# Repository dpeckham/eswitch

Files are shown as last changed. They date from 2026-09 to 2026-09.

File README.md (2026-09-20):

# eswitch — eight-channel house-bank load switch

ESP32-S3 controlled high-side switch with one ATO fuse per channel. Each three-clip
holder accepts a fuse in AUTO (through the PROFET) or BYPASS (direct to the load).

The main KiCad project contains the **334 × 172 mm revision-C design**, with an
independent hardware latch in each channel ahead of both fuse positions. A short
is handled locally; healthy outputs and logic retain their shared supply. See
[circuit and limits](docs/channel-isolation-review.md), the authoritative
[release status](docs/release-status.json), and [BOM cost per board](docs/bom-cost.md).

**Revision C is released for prototype fabrication.** Use the
[bare-board upload ZIP](fab/revision-c/eswitch-revC-gerbers.zip) and
[complete build package](fab/revision-c/eswitch-revC-build-package.zip).
[Order settings and release evidence](fab/revision-c/README.md) accompany them.
ERC, DRC including warnings, routing and schematic parity are all clean;
29 transient cases pass. Bench qualification remains required before service.

The revision-B fabrication release is withdrawn. Its historical ZIP does not
implement the new fault-isolation requirement.

| Item | Requirement |
|---|---|
| Supply | 9.5–16 V; nominal 12 V house bank |
| Simultaneous load | 40 A continuous target, not a qualified rating |
| Channels | CH1–2: 10 A fuse maximum; CH3–7: 5 A; CH8: 20 A |
| Main fuse | Upstream protection; no onboard main fuse; F9 is logic-only, maximum 2 A |
| Outputs | Eight Wuerth 691218410002 direct-entry blocks; pin 1 GND, pin 2 LOAD+ |
| Inputs | Two Wuerth 74650195 M5 ring-lug terminals |
| PCB | 334 × 172 mm, JLCPCB JLC041622-3313, four layers, 2 oz outer/inner, 1.6 mm nominal, ENIG |
| Assembly | Three boards, manual paste + hot air/hot plate; validate one first |
| Procurement | Exact DigiKey MPNs; dated stock is not a reservation and must be refreshed |

Fuse labels identify circuit numbers and maximum fuse values, not guaranteed
continuous currents. USB is for initial bench programming **with battery power
disconnected**; subsequent updates are OTA. Mixed AUTO/BYPASS startup is required.
See [agreed scope](docs/design-constraints.md); deferred installation details have
not been silently assumed.

```sh
mise install
mise exec -- just verify          # saved schematic/PCB; ERC, DRC, parity, pin/silk/geometry checks
mise exec -- just all             # verify + renders; preserves completed routing
mise exec -- just review-package  # clearly unreleased CAM/BOM/schematic/assembly drawing ZIP
mise exec -- just bom             # requires fresh stock evidence; fails when stale
mise exec -- just package         # also requires engineering release for these exact source hashes
python3 -m unittest discover -s tools -p 'test_*.py'
```

`out/verification/manifest.json` binds verification results to the exact source
files and report hashes, including the engineering release documents. The
withdrawn prototype ZIP is retained under `fab/revision-b/` for traceability.
`out/review/` retains an unreleased review snapshot; do not upload it.
`fab/legacy-f76c39e/` and the old OSH Park upload are obsolete.
No order or purchase has been made.

The saved PCB is the authoritative routed design. `just pcb` now creates an
**unrouted candidate under out/**. `just libs` and `just sch` are explicit source
regeneration operations. Checked finish/routing tools replace the old revision-A
coordinate patches in the build recipes. Do not run legacy `finish.py`/`stitch.py`
on revision C. Its one-time migration uses the explicitly saved revision-B snapshot.

[Assembly instructions](docs/assembly.md) · [Channel/input protection](docs/channel-isolation-review.md)
· [Critical review/history](docs/critical-review.md) · [Per-board BOM](fab/digikey/eswitch-digikey-bom.csv)

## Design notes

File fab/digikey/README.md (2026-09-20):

# DigiKey BOM — quantities for ONE module

This is the revision-C BOM, including independent channel breakers. Check
[current release status](../../docs/release-status.json) for fabrication readiness.
[Cost per board](../../docs/bom-cost.md) includes a priced breakdown and an optional
cart with spares where price breaks reduce the total cash cost.

`eswitch-digikey-bom.csv` lists the exact parts needed to assemble **one board**.
Apply your desired number of modules when ordering. No batch multiplier or spare
allowance is included, even though the prototype plan is to build three modules.

Quantity checks: 1 ESP32 module, 24 Keystone 3557 clips, 8 output connectors,
2 input terminals, and 8 branch fuse inserts per board. The clip quantity counts
individual clips, not complete fuse holders.

For manual assembly, choose cut tape (CT) for surface-mount parts where offered,
and the listed bulk/tray packaging otherwise. Digi-Reel fees and full-reel minimum
quantities are unnecessary for this build. Check quantity breaks in the cart:
occasionally a few extra parts cost less than the exact required quantity.

`stock-audit.csv` is a dated inventory observation, not a price quote or stock
reservation. No parts have been purchased here. Installation wiring, input
ring lugs/screws and enclosure hardware are outside this component BOM.

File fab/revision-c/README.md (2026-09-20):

# Revision C — released for prototype fabrication

Upload **[eswitch-revC-gerbers.zip](eswitch-revC-gerbers.zip)** for bare PCBs.
The **[complete build package](eswitch-revC-build-package.zip)** contains the
schematic, 1:1 assembly drawings, BOM, cost breakdown, engineering limits and
verification evidence. Revision-B packages are withdrawn.

The revised board is **334 × 172 mm**. All eight channels have independent
hardware latches ahead of both AUTO and BYPASS. USB edge alignment, exposed-pad
thermal vias, input source vias, twelve mounting holes with hardware clearances,
Kelvin sensing, monitoring, local reset buttons and test points are included.

## Order settings

| Setting | Required value |
|---|---|
| Board | FR-4, four layers, 334 × 172 mm, single PCB |
| Quantity | Five bare PCBs is the offered batch covering three planned assemblies |
| Thickness | 1.6 mm nominal; JLC041622-3313 stackup |
| Copper | **2 oz outer AND inner** |
| Finish / mask / legend | ENIG 1 µin / green / white |
| USB impedance | 90 Ω differential, ±10%; supplied USB-impedance-request.jpg |
| Via covering | Plugged for eligible closed-mask vias only; preserve exposed thermal pads |
| Min via selection | 0.3 mm hole / 0.4–0.45 mm diameter offered option |
| Production files | Confirm Production File = Yes; **disable automatic confirmation** |
| Electrical test | Flying Probe Fully Test |
| Mark | Remove Mark |
| Assembly / stencil | Not ordered; manual assembly plan in build package |

Use the exact layer order F.Cu / In1.Cu / In2.Cu / B.Cu. Preserve separate
PTH/NPTH drills and all supplied pad/mask openings. Read `gerbers/README-fab.txt`
for the complete specification. JLC can reset finish and stackup settings after
an upload: check these values **after** uploading. Approve the manufacturer's
production files manually, including any proposed USB impedance adjustments.

## Checks and remaining qualification

KiCad 10.0.6 ERC, DRC including warnings, unrouted connections and schematic/PCB
parity all pass with zero findings. The native 1195-pin map, fuse geometry and
silkscreen, mounting clearances and 3276 USB reference samples pass. All 29
bounded startup/fault transient cases pass. These are calculations and simulation,
not measurements of an assembled board.

Independent Gerber/Excellon parsing verifies four copper layers, the outline,
1579 plated drill objects and 14 non-plated holes. Exported copper/mask/silk and
top/bottom 3D views were inspected. [CAM evidence](cam-review.json) binds the
final flat upload ZIP to the inspected export; the build ZIP contains a manifest
of every included file and the approved source hashes.

JLC's public parser recognized four layers and 334 × 172 mm and produced top/bottom
previews; [final upload/settings evidence](jlc-upload-review.json) records the exact
upload hash and [configured quote](jlc-configured-quote.png). Its detailed Gerber
viewer requires sign-in. Manufacturer engineering
DFM and production-file approval remain part of the actual order; neither is
claimed as completed here. No cart, order or purchase was submitted.

Assemble and validate one board first. The 40 A aggregate continuous target and
marine installation are not qualified until the documented fault/recovery,
regulator/USB, thermal and mechanical tests pass. See the build package's
`prototype-release.md` and `bring-up.md`.

## Cost, USD observed 2026-09-19

| Purchase | Cost |
|---|---:|
| Exact BOM for one assembly, including fuses and 12 standoffs | $318.40 |
| Optional one-board cart with explicit spares at cheaper price breaks | $299.30 |
| Exact parts for three assemblies | $800.31 total; **$266.77 each** |
| Configured JLC bare-board estimate, five PCBs | $224.39 total |
| Three exact BOM sets plus five bare PCBs | $1,024.70 total; $341.57 per assembly with two spare PCBs |

The PCB figure includes 2 oz on all four layers, ENIG, impedance control and
production-file confirmation. It is an online estimate, subject to manufacturer
file review, not a reserved quote. Shipping, tax, tariffs, assembly, solder/paste
and enclosure-specific screws/washers are excluded. The import BOM remains for
**one assembly**; apply the intended build quantity when purchasing.

[Detailed BOM pricing](../../docs/bom-cost.md) ·
[One-board import BOM](../digikey/eswitch-digikey-bom.csv) ·
[Three-board cost breakdown](../digikey/cost-three-board-build.csv) ·
[Authoritative release status](../../docs/release-status.json)

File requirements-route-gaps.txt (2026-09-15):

# Compatible with KiCad 10's embedded Python 3.11.
numpy==1.26.4

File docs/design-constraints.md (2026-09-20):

# Confirmed scope — amended 2026-09-19

- Nominal 12 V house-bank distribution; 40 A simultaneous continuous **target**.
- Guaranteed operating-input design range: **9.5–16 V**, revised with the owner's
  approval on 2026-09-16 to provide headroom for the latch-off controller.
- Eight channels retain their maximum branch fuse sizes: 10/10/5/5/5/5/5/20 A.
- Mostly VHF/GPS and other electronics, lights, and intermittently operated pumps.
  Exact models, inrush/stall currents and channel allocation are unspecified.
- External relays are an owner-provided fallback for pumps. No onboard relay
  circuitry is requested. Motor current must use the relay's separately protected
  power circuit if the intent is to keep it off this PCB; switching only the coil
  does not qualify an arbitrary relay or pump combination.
- Initial USB programming takes place with the house-bank connection disconnected;
  later firmware updates are OTA. Preserve USB-only logic power and boot/reset
  access. Simultaneous house-bank/USB operation is not a required operating mode.
- Three manually assembled boards; paste and hot air/hot plate are available.
  All exact BOM parts must be available from DigiKey in the required quantities.
  On 2026-09-19 the owner clarified that the published BOM must be **per board**;
  the owner applies ordering multiples. Never embed the planned batch count in it.
- Direct-entry screw output terminals; upstream main fusing, no onboard MIDI fuse.
- Power may be applied with a **mixture of AUTO and BYPASS fuse positions**.
  Unloaded startup is not an allowed design assumption. Review startup and
  automatic recovery with connected loads, including MOSFET linear-mode SOA;
  parallel MOSFETs must not be assumed to share startup current equally.
  Fuse positions are changed only with battery power disconnected, never live.
- On 2026-09-19 the owner explicitly accepted **latch-off at a lower startup
  load while retaining the 40 A continuous target**. Successful full-40-A BYPASS
  startup is not required. Select and document the lower startup envelope; do
  not weaken fault protection to force full-load startup.
- On 2026-09-19, after reviewing branch/input protection coordination, the owner
  selected: **"Isolate the faulty channel so healthy outputs keep operating."**
  This supersedes accepting whole-board latch-off as the response to an output
  short. It applies to both AUTO and BYPASS; the ESP32 and healthy outputs must
  remain operating. Protection must work without firmware, including during
  MCU reset. See [channel isolation review](channel-isolation-review.md).
- The earlier acceptance of lower-load startup does not authorize one shorted
  branch to prevent otherwise admissible healthy loads from starting. Include
  a short present at power-up as well as a short applied during operation.
- Retain hardware latch-off/no automatic retry as the fault-response design
  basis, now local to the faulty branch. A genuine shared-input fault or
  excessive aggregate healthy startup load can still require a common shutdown;
  ordinary single-output shorts must not be reclassified as shared-input faults.
  No reliance on ESP32 firmware to enforce protection or retain a fault latch.

## Deliberately outside this review's supplied inputs

The owner asked not to pursue battery chemistry/model, charger/settings, upstream
fuse/feeder details, enclosure/location or mechanical restrictions. These remain
**unknown**, not verified safe. Do not silently infer battery fault current,
transient amplitude/energy, ambient temperature or available cooling. Board-level
corrections can proceed without treating installation qualification as complete.
On 2026-09-15 the owner authorized enlarging the PCB for electrical reliability,
selecting a fabrication service with heavier copper, and initially designing for 9–16 V
operation with reverse-polarity blocking and overvoltage disconnection around
17 V. The lower operating limit is now 9.5 V as recorded above. Higher-voltage
charging/equalization is allowed to disconnect the outputs.

The earlier request to defer hardware testing referred to the **host PC freeze
investigation**, not PCB validation. Prototype bring-up and thermal/load testing
remain necessary before assigning a measured continuous-current or marine-service
rating. Ordering prototype bare boards precedes those tests.

## Pump and relay boundary

Short run time reduces average heating but does not remove startup/stall current
or inductive turn-off stress. Do not raise fuse limits on that basis. A relay coil
also stores inductive energy; use suitable coil suppression (built-in or external)
and observe polarity where a diode is fitted. [TI inductive-load guidance](https://www.ti.com/document-viewer/lit/html/SLVAF04).

Direct pump use is not qualified, nor is this board approved as the sole automatic
bilge-pump or other safety-critical power/control path. Those are installation and
prototype-validation questions, not resolved by the owner's relay fallback.

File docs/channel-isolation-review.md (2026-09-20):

# Revision C channel protection

Revision C implements the requested behavior: an output fault is handled by that
channel's hardware breaker, in both AUTO and BYPASS. Fabrication status is recorded
in [release-status.json](release-status.json); this document is not a release token.
The withdrawn revision-B Gerbers do not implement this circuit.

## Circuit and coordination

Battery → LM74800 reverse-polarity stage → TPS2492 common startup/backup stage →
shared bus. The logic supply uses this bus. Each channel then has its own TPS2492,
single shunt and LFPAK88 pass MOSFET, ahead of the three-clip fuse COM terminal.
AUTO passes through the PROFET; BYPASS goes directly from the fuse to the output.
Both positions retain the new hardware breaker. The fuse remains backup protection.

U21–U28 are **TPS2492PWR**, with Q11–Q18 **PSMN1R8-80SSEJ**. A fault latches only
its local controller. SW3–SW10 pull the corresponding UVEN low to reset that
channel. A persistent fault trips again after reset. MCU reset or stopped firmware
does not disable protection. Loss of input/enable can clear these volatile latches;
there is no nonvolatile fault memory and no timed automatic retry.

| Channels | Maximum fuse | Shunt | Current-limit screen | Startup load envelope |
|---|---:|---:|---:|---|
| 1, 2 | 10 A | 4 mΩ | 10.61–14.63 A | 10 A full-voltage resistor + 1000 µF actual |
| 3–7 | 5 A | 8 mΩ | 5.31–7.31 A | 5 A full-voltage resistor + 1000 µF actual |
| 8 | 20 A | 2 mΩ | 21.23–29.26 A | 10 A full-voltage resistor + 1000 µF actual |

CH8 retains its 20 A fuse ceiling and has a lower startup envelope. Electronic
constant-power loads and motors need individual bench checks; this resistor model
does not qualify every load drawing the same steady current. All channel currents
sum toward the **40 A continuous target**, which still requires thermal measurement.

The common R20 is 0.5 mΩ, giving an 87.80–112.82 A backup limit. Forty amperes of
healthy load plus the largest branch limit is below its minimum threshold. This
common limit is not a 40 A continuous thermal breaker. R17/R18 set approximately
432 W nominal common MOSFET power limiting; C18/C25/C28 total 36 nF C0G. The
maximum fault timer is below 10 ms and the calculated worst power is below the
single-device 10 ms SOA at a 60 °C mounting base, including graph reserve.

MAIN_PG_N drives Q6 to enable branches after the shared reservoir charges. The
inverter uses the controller's reference, independently of 3V3. Twenty-four
35SVPF120M capacitors provide 2880 µF nominal on the common bus. This reservoir,
the raised common limit and local gate discharge all matter during a live short;
current-threshold arithmetic alone does not establish isolation.

Each local TIMER has two 100 nF U2J capacitors, giving an 18.42–55.47 ms initially
discharged timeout screen. U2J temperature dependence is included. PROG divider
resistors are 0.1%, 25 ppm/°C; the calculations reserve 1% total resistance error.
Q31–Q38 FMMT720TA PNP devices boost gate discharge through 10 Ω, with 100 Ω between
the controller and pass-MOSFET gate. A local STPS41L60CG clamp handles output wiring
inductance. A separate 10 Ω/Schottky network protects each controller's OUT sense
pin from negative switching spikes. Output LEDs also have reverse clamps.

See [exact corner calculations](channel-isolation-calculations.json) and the
[transient sensitivity results](channel-isolation-transients.json). The latter
uses TI's controller model with latch selection and PSpice Boolean syntax preserved.
The ideal TIMER-clamp TABLE can also use an equivalent piecewise-linear
behavioral current source for ngspice compatibility. The implementation and
numerical options are recorded per case. The fixture includes three controllers (common, faulted and healthy), finite gate capacitance and
3 nF drain–source capacitance per MOSFET, a 5 mΩ +
1 µH source and a 10 mΩ + 100 nH short loop. It checks pre-existing and live faults,
loaded startup, bus voltage, healthy-controller state and pass-MOSFET stress.
The MOSFET is an approximate level-1 model with gate-charge sensitivity, not a
manufacturer transient model. This is design screening, not measured hardware.

An [additional six-case study](all-channels-transients.json) models all nine
controllers with 1,000 µF on every output, at 9.5 V and 16 V. It combines the
most sensitive common-controller corner with the strongest, slowest local
controllers. All-channel startup, a pre-existing CH8 short and a live CH8 short
pass. Startup/live loads total 40 A before the fault; the pre-existing-short
case places 40 A on the seven healthy outputs, with 2 A auxiliary in every case.
The lowest live-fault bus voltage is 9.251 V; the largest combined SOA utilization
is 0.728. PROG follows each controller's reference during power-up, as the real
divider does. Some numerical variants initialize the unpowered circuit with
uncharged capacitors (`uic`); this and solver/TIMER implementations are recorded.

SOA uses Nexperia's published curves with all common-stage current attributed to
one MOSFET, a 60 °C mounting-base limit and 10% graph reserve. Live-fault stress is
split into the first 10 µs, the next 90 µs and the limiting tail; respective 10 µs,
100 µs and 100 ms rectangular-envelope utilizations are added conservatively.
Low-VDS points are compared at the curve's higher-voltage current knee, avoiding
mistaking the hot RDS(on) edge for a cold-device thermal failure boundary.

The bus can dip briefly during a fault. Healthy-load acceptance requires measuring
that dip against the actual equipment's minimum voltage and hold-up, plus checking
3V3 and ESP32 reset. The simulated source impedance is an explicit fixture model;
it is not a guarantee for arbitrary battery cables or converter loads. The first
assembled board must pass [bring-up](bring-up.md) before a service rating is assigned.

## Layout and assembly

The board is 334 × 172 mm, four layers with 2 oz outer and inner copper. Twelve M3
holes add support beside the channel groups. Each has a 4 mm copper exclusion
radius; select hardware fitting that envelope. J4's mating edge is aligned to the
board edge. Its NPTH copper clearance is at least 0.2 mm and shield-pad annular
rings are enlarged for 2 oz fabrication. Q1/Q2 DGATE uses In2, with extra source
vias so the bottom source copper is no longer divided by the gate track.

CH1, CH2 and CH8 have eight in-pad thermal vias; the other PROFETs have at least
six. These vias connect to VS, not ground. Local pass-FET drain/source via fields
and broad branch pours carry power. No signal tracks may cut the In1 ground plane.
The shared shunt has a close F.Cu Kelvin pair. USB retains its dedicated In2 ground
reference and the selected 90 Ω differential geometry.

JLC's published component-PTH annular-ring requirement (0.254 mm for 2 oz) and its
via-diameter requirement are separate table entries. Via diameter is at least
0.20 mm larger than drill in this design, exceeding the published preferred
0.15 mm difference. Check the final CAM/DFM results against the actual order.
[Fabrication capabilities](https://jlcpcb.com/capabilities/Capab).

The Panasonic F12 recommended lands are 13.1 mm overall, 4.3 mm inner gap and
1.9 mm width; the selected 10 × 12.6 mm footprint matches them. FMMT720 pinout is
1 base, 2 emitter, 3 collector. See the
[Panasonic mounting specification](https://industrial.panasonic.com/cdbs/www-data/pdf/AAB8000/AAB8000COL10.pdf)
and [FMMT720 datasheet](https://www.diodes.com/assets/Datasheets/FMMT720.pdf).

## Monitoring and test points

IN1 moves from IO7 to IO15. IO5 measures IMON (nominal 24 mV/A with the new shunt),
and IO7 measures the shared bus through a 115 kΩ / 10 kΩ divider (0.08 V/V).
Both ADC paths have series resistance, filtering and Schottky clamps. MAIN_FLT_N
uses IO42; branch FLT1–FLT8 use IO16/17/18/35/36/37/39/40. Fault outputs have
3V3 pullups. Firmware must use this revised pin map.

TP1–TP16 expose GND, BATT_RAW, BATT_MID, HS_VCC, HS_SENSE, HS_TIMER, HGATE_MAIN,
+12V, VIN, +3V3, MAIN_IMON, MAIN_FLT_N, MAIN_PG_N, BR_ENABLE, ADC_IMON and ADC_BUS.
TP17–TP24 expose branch TIMER1–TIMER8. Ground-referenced instruments must never
short a high-side Kelvin or gate node to ground through their probe clips.

Primary circuit references: [TPS2492](https://www.ti.com/lit/gpn/tps2492),
[PSMN1R8-80SSE](https://assets.nexperia.com/documents/data-sheet/PSMN1R8-80SSE.pdf),
[WSLP shunts](https://www.vishay.com/docs/30122/wslp.pdf).

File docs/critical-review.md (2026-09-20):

# Critical review — revision C, 2026-09-19

The current implementation is described in [channel protection](channel-isolation-review.md).
It adds independent hardware breakers ahead of every AUTO/BYPASS fuse, coordinated
common startup, a shared reservoir, monitoring, test points and the mechanical/
thermal layout corrections. Current verification and fabrication status are in
[release-status.json](release-status.json). Revision-B Gerbers are withdrawn.

[Power review](power-review.md), [assembly](assembly.md) and [bring-up](bring-up.md)
describe the current prototype scope. No measured continuous-current or marine
service rating is assigned before the first assembly is tested. The dated
[BOM cost](bom-cost.md) distinguishes installed quantities from optional spares.

The following revision-A material is historical; its implementation status and
check counts do not describe the current board.

## Historical revision-A review (2026-09-15)

## Owner's requirements

Nominal 12 V boat house bank, DC–DC charged from the alternator-fed bank; no direct
starter/alternator connection. Battery chemistry/model and charger/settings remain
unknown. Total continuous target is **40 A**, not 65 A. Channel targets remain
10/10/5/5/5/5/5/20 A. Use direct-entry screw outputs and **upstream main fusing, no
onboard MIDI**. Three boards will be assembled manually with paste and hot air/hot
plate available. Exact BOM parts must be in stock at DigiKey in build quantities.

## Implemented corrections

| Finding | Correction |
|---|---|
| B360-13-F is SMC, not the fitted SMA | D1/D2/D4 use B360A-13-F. [Diodes datasheet](https://www.diodes.com/datasheet/download/B360A.pdf) |
| Output part was pluggable, not direct-entry | Eight Wuerth 691218410002 two-pole blocks, 7.62 mm pitch, pin 1 GND/pin 2 LOAD+. Component rating 30 A/pole, 24–10 AWG. [Drawing](https://www.we-online.com/components/products/datasheet/691218410002.pdf) |
| Keystone 8196 inputs were only 30 A each | Replace with Wuerth 74650195, nine solder pins, M5 blind thread. Positive and return ratings never add. New hole pattern requires local signal rerouting. [Old terminal](https://www.keyelco.com/product.cfm/product_id/1533), [replacement](https://www.we-online.com/components/products/datasheet/74650195.pdf) |
| LED resistor power margin | R107–R807 become 10 kΩ: 28²/10000 = 78.4 mW even with a shorted LED. Ambient derating still applies. |
| Fuse identification | Each channel holder has its circuit number and maximum fuse rating: CH1–2 10 A, CH3–7 5 A, CH8 20 A. F9 is marked LOGIC MAX 2A on the SMD side. Output labels identify channels without implying a qualified continuous-current rating. |
| Fabrication minima | Copper-edge clearance 0.4 mm; minimum through-drill 0.254 mm; enlarged ESP32 thermal holes; project rules now persist reliably. |
| Connectivity and parity | The terminal migration is fully routed. Native KiCad reports 0 unrouted connections and 0 schematic/PCB parity issues; the independent 497-pin assignment check agrees. |
| ESP32 antenna | Restored an all-copper/pad/via keepout over the portion of the antenna region that overlaps the PCB, moved C10/C1/C2 clear, and rerouted VIN/3V3. The module antenna remains intentionally beyond the board edge. |
| U3–U7 identification | BTS70081EPRXUMA1 is **BTS7008-1EPR**, not EPP. Correct symbol/value/datasheet. Pinout matches, but use EPR specifications: 8.8 mΩ typical, 16 mΩ maximum at 150 °C, nominal kILIS 14500. [Datasheet pp. 2, 5–6](https://www.infineon.com/assets/row/public/documents/10/49/infineon-bts7008-1epr-datasheet-en.pdf) |
| Stock/assembly | Replace unavailable same-value/package order codes, include LFS button suffix, and generate a three-board purchasing list with dated stock evidence. U11 becomes SRV05-4HTG-D, four steering channels paired externally onto two data nets. The newly unavailable CC0603KRX7R9BB104 is replaced by the same-size/value/voltage X7R Yageo CC0603JRX7R9BB104 with tighter ±5% tolerance. [Littelfuse datasheet](https://www.littelfuse.com/assetdocs/littelfuse-tvs-diode-array-srv05-4htg-d-datasheet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), [Yageo specification](https://www.yageogroup.com/download/specsheet/CC0603JRX7R9BB104) |

The BOM contains 46 line items including branch fuse inserts and standoffs. Its
stock observations are not reservations. See [assembly notes](assembly.md),
[stock evidence](digikey-stock.json) and `fab/digikey/`. No automatic unreviewed
cross-manufacturer substitutions are permitted.

## Order-stopping issues still open

### Input protection

SMBJ26A's specified clamp reaches 42.1 V, above the PROFET's 28 V normal absolute
maximum and 35 V **specified suppressed** load-dump allowance. “26” is not the
clamp voltage. The house-bank arrangement changes expected disturbances but does
not establish their maximum amplitude or energy. [SMBJ26A data](https://www.littelfuse.com/products/overvoltage-protection/tvs-diodes/surface-mount/smbj/smbj26a),
[PROFET limits](https://www.infineon.com/assets/row/public/documents/10/49/infineon-bts7008-1epr-datasheet-en.pdf).

The unidirectional TVS forward-biases with reversed battery polarity. No main
reverse-blocking stage is fitted. PROFET ReverseON is not board-wide reverse
protection, especially in BYPASS. F9 protects only the logic branch. Coordinate
the reverse protection, TVS, upstream fuse/holder, feeder and available bank fault
current. A candidate 50 A fuse is **not yet approved**. A PCB PTC is not a proven
substitute for battery fault interruption. Battery/charger details are needed to
validate the input envelope and charging/equalization limits.

### Buck power stage and USB-only supply

U9 is near (29.8, 9.0) mm while catch diode D4 is near (24.5, 24.5) mm. The switch
path and roughly 54 mm feedback route are not a compact converter layout. Place
input ceramic, catch diode, inductor and local ground together; keep feedback
quiet and compensation local. Recheck loop compensation and effective capacitance
after layout changes. [TI TPS54360B layout guidance](https://www.ti.com/lit/ds/symlink/tps54360b.pdf).

TPS54360B needs at least 4.5 V at VIN. A valid low USB VBUS minus D2's forward drop
falls below that requirement, so USB-only startup is not guaranteed. Correcting
the diode package does not fix this. Use a topology with guaranteed low-voltage
headroom and test startup/load steps, USB current limits and enumeration behavior.

### USB layout

U11 is about 13 mm from J4 and the data traces are not a deliberately controlled
differential pair. Move ESD protection to the connector with a short ground path,
route over continuous reference copper and verify impedance on the actual stackup.
Review series-resistor provisions near the MCU. The ESD part substitution is not
port-level ESD qualification. Initial programming is explicitly USB-only with the
house bank disconnected, so simultaneous self-powered attach is outside the agreed
operating mode. If that changes, add VBUS detection and verify detach/re-attach.
[Espressif USB guidance](https://docs.espressif.com/projects/esp-usb/en/latest/esp32s3/usb_device.html).

### Current, thermal performance and branch fuses

OSH Park standard four-layer copper is **1/0.5/0.5/1 oz**, not 1 oz everywhere or
2 oz on the top. Analyze both common source and return paths, terminal pin fields,
contact resistance, vias and signal-induced bottlenecks for 40 A. Width alone is
not proof. [OSH Park stackup](https://docs.oshpark.com/services/four-layer/).

At CH8's hot resistance limit, 20² × 4.8 mΩ is about 1.92 W in the switch alone.
The datasheet reference board's thermal resistance does not qualify this layout.
Add close thermal vias and effective spreading copper. **PROFET exposed pads are
VS, not ground.** Validate temperature rise at 40 A simultaneous load with the
worst load distribution, enclosure/ambient, inrush and fuse-clearing conditions.
[BTS7002 datasheet](https://www.infineon.com/dgdl/Infineon-BTS7002-1EPP-DataSheet-v01_11-EN.pdf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).

The ATOF derating table permits 18 A through a nominal 20 A fuse at 20 °C and 15 A
at 65 °C; a 10 A fuse permits 8 A at 65 °C. Printed fuse ratings are therefore not
continuous channel ratings. Do not simply upsize: review wire, holder, terminals,
copper, inrush and clearing time first. [Littelfuse ATOF table](https://www.littelfuse.com/assetdocs/littelfuse_datasheet_287_atof_r2.7.pdf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).

### Physical fit

Print custom footprints at 1:1 and check real clips, a blade fuse and both terminal
types. The direct-entry row is taller/deeper and overhangs the edge; input hardware
needs a validated lug/screw stack and strain relief. Generated 3D envelopes do not
prove pin tolerances, fuse retention or screw access. See [assembly.md](assembly.md).

## Additional checks

- Review each variant's application network, including the absent 47 nF
  VS-to-device-GND capacitor. Device GND is separated from board GND by RGND.
- Off-state open-load diagnosis needs the external pull-up/test circuit, which is
  absent. Do not promise it in firmware/UI. Calibrate current sensing and use
  variant-specific limits rather than one nominal kILIS for every channel.
- Check repetitive inductive turn-off energy and cable inductance. Internal clamps
  are not unlimited. Verify OFF states through reset, programming and brownout.

## OSH Park approval-page notes

The [submitted approval page](https://oshpark.com/uploads/11HAlFYE/approval/new)
is a prior-revision manufacturing preview, not electrical approval. Its notes cover
closed outlines, plating where holes intersect copper, unsupported blind/buried or
overlapping holes, drill-size adjustment and silk clipping at exposed copper/edges.
The rendered layers/outline do not qualify current capacity or component choices.

The original 0.2 mm module drills and 0.3 mm copper-edge spacing conflicted with
the service's 0.254/0.381 mm limits; the project now uses 0.254/0.4 mm. Reinspect
layer order/polarity, finished holes, annular rings, slots and clipped labels on a
**new upload after all fixes**. Do not order the existing upload for this revision.
[OSH Park rules](https://docs.oshpark.com/services/four-layer/).

## Release conditions

Current routed snapshot: ERC reports 0 violations; copper DRC reports 0 errors and
0 unrouted items; native schematic/PCB parity reports 0 issues; the independent
assignment check matches all 497 physical pins; and the fuse-silk checker verifies
all eight circuit/max-fuse labels plus the 2 A logic-fuse label.

The 26 remaining DRC warnings were inspected: two are the intentionally clipped
silk outline of the overhanging U10 antenna, one is the deliberately modified U10
footprint (larger thermal drills/body-only courtyard), 14 are duplicate outline
ends where adjacent output-terminal bodies touch, and nine are cosmetic reference
text/outline or mask clipping on the SMD side. None involves copper clearance or
the fuse labels. They should still be reinspected on the final vendor preview.

The PCB/database checks and final plots now pass their release recipes. Close the
remaining electrical/layout and physical-fit blockers before producing a prototype
order. The owner has deferred bench testing; it remains required before claiming
continuous ratings or marine-service suitability. Fabrication is gated by
`release-status.json`; archived packages are not current releases.

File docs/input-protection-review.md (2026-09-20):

# Input protection — prototype review, 2026-09-19

**Fabrication release withdrawn: channel fault isolation redesign required.**
The owner requires healthy outputs and the controller to keep operating during
a single-output short in AUTO or BYPASS. See [the new decision and design work](channel-isolation-review.md).
The TPS2492 topology below is implemented in revision B but does not establish
that behavior. Its former release and required-behavior sections are historical.
Read the [withdrawn prototype release](prototype-release.md),
[power findings](power-review.md) and [clamp limits](input-clamp-review.md).
Historical sections below explain the rejected stage and superseded candidates.

## Current implementation

- LM74800 U12 drives only the Q1/Q2 reverse ideal-diode bank.
- R20: CSS4J-4026R-1L00F, 1 mΩ four-terminal shunt. Separate Kelvin sense traces.
- U14: TPS2492PWR, hardware power/current limiting and fault latch-off.
- Q3/Q4: PSMN1R8-80SSEJ, 80 V enhanced-SOA LFPAK88, separate 10 Ω gate resistors.
- R12/R13: 115 kΩ/10 kΩ, 0.1%, OV divider. R14/R15: 56.2 kΩ/10 kΩ, 0.1%, UV divider.
- R17/R18: 8.25 kΩ/1 kΩ, 1%, PROG divider; nominal power limit about 216 W.
- C18: 10 nF C0G, nominal fault timeout about 1.48 ms. These nominal values are
  **not** a guaranteed startup or fault-survival rating.
- D3: SMCJ24CA input clamp; D6: SMCJ16A protected-bus clamp;
  D7: STPS41L60CG-TR freewheel clamp. Coordination reviewed; measure energy and overshoot under the prototype plan.

TPS2492 fault latch resets on UVEN-low or internal UVLO, as well as deliberate
battery removal. A sufficiently deep input brownout therefore resets it; it is
not a nonvolatile latch. No timed automatic retry is designed in. Characterize this
distinction and loaded UV/OV recovery during prototype qualification.

[TI TPS2492 datasheet](https://www.ti.com/lit/ds/symlink/tps2492.pdf),
[Nexperia PSMN1R8-80SSE datasheet](https://assets.nexperia.com/documents/data-sheet/PSMN1R8-80SSE.pdf),
[Bourns shunt drawing](https://bourns.com/docs/product-datasheets/css4j-4026.pdf),
[ST freewheel diode datasheet](https://www.st.com/resource/en/datasheet/stps41l60c.pdf).

## Required behavior

- 9.5–16 V input, 40 A simultaneous continuous design target (owner approved).
- Reverse-polarity blocking and overvoltage disconnection around 17 V.
- Upstream battery fuse; no onboard main fuse.
- Startup with a mixture of AUTO and BYPASS positions is required. Include
  recovery after undervoltage/overvoltage; do not assume all loads are off.
- Load models, total input capacitance and motor inrush are unspecified.
- Historical revision-B choice: latch the entire board on excessive startup
  current or an input overcurrent fault. The later channel-isolation decision
  supersedes treating an output short as an acceptable cause of whole-board
  latch-off. Automatic retry and firmware-dependent protection remain excluded.
- Preserve the separate USB-only bench supply; never require the battery for
  initial programming and never connect battery and USB together in this mode.

## Why the superseded stage was rejected

The superseded PCB's Q3/Q4 devices are BSC016N06NS, driven together from LM74800 HGATE
with a 10 nF gate-to-ground slew network. HGATE sources 39–75 µA. Both intrinsic
gate charge and the external capacitor affect the loaded transition. The relevant
MOSFET criterion is linear-mode safe operating area (SOA), not just on-resistance
or pulse drain-current rating. Check a single device carrying the startup stress;
threshold mismatch prevents assuming equal sharing between parallel switches.

[TI LM7480-Q1 datasheet](https://www.ti.com/lit/ds/symlink/lm7480-q1.pdf),
[Infineon BSC016N06NS datasheet](https://www.infineon.cn/assets/row/public/documents/24/49/infineon-bsc016n06ns-datasheet-en.pdf),
[Analog Devices explanation of parallel hot-swap FET startup stress](https://ez.analog.com/power/f/q-a/549834/ltc4368-or-other-and-mosfet-in-parallel).

Merely reducing C18 increases capacitive inrush. Merely increasing it extends the
time dissipating power with resistive or electronic BYPASS loads connected.
Neither is an independently justified fix. An upstream branch/battery fuse is
not a microsecond/millisecond MOSFET SOA limiter.

## Historical candidate investigation (superseded by selection above)

- **PSMN1R8-80SSEJ:** 80 V, enhanced-SOA LFPAK88, substantially larger land pattern
  than the current PG-TDSON-8. DigiKey product page showed 1,884 available on
  2026-09-16. Requires a new symbol/pin mapping (gate 1, sources 2–4, drain mounting
  base), footprint and copper. Must still check gate-charge tolerances, case
  temperature and loaded startup; the SOA designation is not a blanket approval.
  [Manufacturer datasheet](https://assets.nexperia.com/documents/data-sheet/PSMN1R8-80SSE.pdf),
  [DigiKey](https://www.digikey.com/en/products/detail/nexperia-usa-inc/PSMN1R8-80SSEJ/27351652).
- **TI CSD18540Q5B/BT:** not selected because the reviewed DigiKey pages showed
  no stock. Do not add to the BOM without a new availability check.
- **LM74502H:** faster gate drive, but no reverse-current blocking and its
  datasheet expressly excludes the low-drive part's simple inrush circuit.
  Faster switching alone does not bound capacitive inrush. Not a drop-in cure.
  [TI datasheet](https://www.ti.com/lit/ds/symlink/lm74502-q1.pdf).
- **Current-limited hot-swap controller:** under consideration so an excessive
  startup load can disconnect without destroying the pass devices. Requires
  sense-resistor sizing, fault timeout/foldback analysis, a suitable SOA FET,
  and hardware latch-off (owner-confirmed). This is an additional
  protection function, not a replacement for the upstream battery fuse.

## Review disposition

The owner accepted lower-load startup latch-off. The selected envelope,
analytical checks, twelve gate/transient sensitivity cases and derated single-FET
SOA comparison are recorded in [prototype-release.md](prototype-release.md).
Those reviews supported the earlier three-prototype release, now withdrawn.
The branch/common coordination and layout work in the channel-isolation review
must be completed before a replacement fabrication release.

The clamp review establishes voltage coordination and initial test restrictions;
it does not qualify unspecified cable/load energy. Physical startup, hot restart,
live-short, negative OUT/clamp, brownout and thermal measurements remain required
before production release. Follow [bring-up.md](bring-up.md).

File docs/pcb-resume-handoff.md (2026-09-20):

# Revision C handoff — 2026-09-19

The owner requires single-channel fault isolation in AUTO and BYPASS, independent
of firmware. The current schematic implements eight local TPS2492 breakers and
coordinated shared startup. The board is 334 × 172 mm with twelve mounting holes.
See [channel protection](channel-isolation-review.md) and the authoritative
[release record](release-status.json) for implementation details and current status.

The saved PCB is authoritative. Do not rerun legacy migration or board-generation
scripts on it: that would replace completed placement and routing. Revision-B
Gerbers remain withdrawn. Current manufacturing exports belong in `fab/revision-c`.

The purchasing BOM contains 67 exact-MPN lines, with quantities for one assembly,
eight fuses and twelve standoffs. The purchaser applies the desired build quantity.
[BOM cost](bom-cost.md) records dated USD pricing and the optional spare-parts cart.

Before packaging, run `just verify`; ERC, DRC including warnings, unrouted items
and schematic parity must all be zero, with source-bound analytical and transient
evidence. Packaging requires a matching approved prototype release record.
Assemble one board first and complete [bring-up](bring-up.md) before assigning a
40 A continuous or marine-service rating.

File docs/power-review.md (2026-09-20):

# Revision C power review — 2026-09-19

The current circuit, coordination limits and model assumptions are documented in
[channel protection](channel-isolation-review.md). The source-bound CAD and
fabrication decision is in [release-status.json](release-status.json). Revision-B
input-stage calculations and startup explanations are historical; their 1 mΩ
shunt and 10 nF timer do not describe revision C.

## Current protection and thermal scope

Each AUTO/BYPASS channel has a TPS2492 hardware breaker upstream of its fuse.
The common startup/backup stage uses a 0.5 mΩ shunt, 36 nF C0G timer and the
existing approximately 432 W nominal power setting. Its 87.80–112.82 A current
limit leaves room for a local branch to clear a fault while healthy channels
remain supplied. It does not enforce the 40 A continuous thermal target.

The channel calculations include shunt and precision-divider error, timer
current/threshold/capacitance corners, startup charge and derated single-FET SOA.
The transient study additionally includes the shared 2880 µF reservoir, its ESR,
source and fault-loop inductance, gate-discharge boosters and a healthy controller.
See [calculations](channel-isolation-calculations.json),
[transient evidence](channel-isolation-transients.json) and their reproducible tools.

The 334 × 172 mm, four-layer board uses 2 oz outer and inner copper. Explicit
power pours and via arrays carry branch current; the PROFET thermal vias connect
to VS. The input reverse-FET gate route no longer divides the bottom source pour.
In1 remains a ground reference. Thermal-via count and copper dimensions are
geometric evidence, not measured temperatures or an installation current rating.

Forty amperes aggregate continuous operation, 20 A CH8 operation, actual load
startup and healthy-equipment ride-through still require the instrumented tests
in [bring-up.md](bring-up.md). The model's 60 °C MOSFET mounting-base ceiling must
be confirmed in the intended cooling arrangement. Build one assembly first.

## Buck capacitance and USB

The output-capacitor selection is corrected. C7/C8/C12/C13 now use
**GCM32ER70J476KE19L, 47 µF/6.3 V X7R ±10%, 1210**. The footprint and copper
are unchanged. Four parts provide 188 µF nominal on the **3.3 V rail only**.
Do not use these 6.3 V parts on VIN or battery nets.

`python3 tools/buck_analysis.py --check` checks the exact selected model, part
assignments and saved calculations. Murata SimSurfing's combined temperature,
DC-bias and 10 mVrms AC model was sampled from −55 to 125 °C in 5 °C steps and
0–3.7 V in steps below 0.04 V. The lowest sample is 20.503 µF per part. Applying
10% initial tolerance and a further 20% engineering reserve gives
**4 × 20.503 × 0.90 × 0.80 = 59.05 µF**, 47.6% above TI's 40 µF requirement.
Temperature and bias are already included in the model; they are not deducted
twice. The extra reserve is a design allowance for unmodelled variation/ageing,
not a manufacturer-guaranteed tolerance. Sampled typical data do not establish
a guaranteed continuous minimum.

The exact-model evidence gap is closed for engineering screening. Production
acceptance still requires fitted-capacitor/rail validation, stability and startup
measurements. The larger bank changes startup charge; repeat USB input-current
measurements with the selected parts. The calculation does not certify USB
current-budget compliance. See [saved calculation](buck-capacitance-calculations.json)
and [manufacturer model samples](evidence/buck-capacitance-murata.json).

The superseded GRM32ER71A226KE20L selection had no exact K-tolerance model in the
retrieved catalog. Its related M-tolerance model was not used as substitute proof.
The new exact part is listed active and the 2026-09-19 DigiKey page audit showed
106,406 available against 12 required. Inventory observations may be cached and
must be reconfirmed at checkout.

The saved B.Cu USB data traces use 0.235 mm width. The geometry check samples their
centres and both copper edges every 0.1 mm against filled In2 GND and passes
3,276 positions. Pair path lengths before the series resistors are approximately
48.54 and 52.18 mm; MCU-side segments are 2.23 mm each. The 3.64 mm mismatch and
connector breakouts still require functional USB review; the sample check is
not an impedance field solver or USB certification. The exact selected stackup
is recorded separately. Bench startup/current-budget testing remains open.

Sources: [TI TPSM63603 datasheet, Table 7-1](https://www.ti.com/lit/ds/symlink/tpsm63603.pdf),
[Murata capacitance-bias guidance](https://www.murata.com/en-us/support/faqs/capacitor/ceramiccapacitor/char/0005),
[Murata SimSurfing](https://ds.murata.com/simsurfing/mlcc.html),
[JLCPCB four-layer 2 oz trace/space capability](https://jlcpcb.com/pcb-fabrication/fr4-pcb).

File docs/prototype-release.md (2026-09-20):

# Revision C prototype fabrication scope

The authoritative approval and exact source hashes are in
[release-status.json](release-status.json). Approval requires a passing saved-design
verification manifest and closure of the listed fabrication blockers. This document
alone does not release a board. Revision-B Gerbers are withdrawn and historical.

The release scope is prototype bare-board fabrication and three manual
assemblies, with one assembled and validated first. No measured 40 A continuous
or installation rating exists. Hardware measurements follow delivery; they are
not prerequisites to ordering a correctly reviewed prototype.

Revision C adds eight independent TPS2492 hardware latches ahead of AUTO and
BYPASS. [The circuit review](channel-isolation-review.md) records protection
settings, startup envelope, semiconductor stress, monitoring and layout changes.
The common protection remains as startup control and backup for shared faults.

Order **334 × 172 mm, four layers, JLC041622-3313, ENIG, 2 oz outer and inner,
1.6 mm nominal**. Preserve the USB reference stackup and geometry. The package
contains separate PTH/NPTH drills, all copper/mask/silk/paste layers, a schematic,
1:1 assembly drawings, the exact one-board BOM and its price breakdown. Select
an offered bare-board batch quantity covering the planned three assemblies.

Select **90 ohm differential impedance control, +/-10%**, and include the supplied
`USB-impedance-request.jpg`. Select **Confirm Production File**, with automatic
confirmation disabled. JLC now offers **Plugged** as its free replacement for
Tented: the order notes restrict ink plugging to eligible closed-mask 0.30/0.40 mm
via holes. Preserve exposed thermal-pad openings, solderable component holes and
NPTH holes. Thermal vias under pads remain open for this manual prototype build.
These settings follow JLC's [via process instructions](https://jlcpcb.com/help/article/pcb-via-covering).

The startup envelope is 9.5–16 V with at most 1000 µF actual capacitance per
branch, plus a resistor drawing 10 A at full voltage on CH1/2/8 or 5 A on CH3–7.
CH8 retains its 20 A maximum fuse but has a lower startup-load allowance.
A shorted branch must not prevent otherwise admissible healthy loads starting.
Constant-power converters, motors, cable impedance and residual TIMER charge
need the explicit tests in [bring-up.md](bring-up.md).

The connector and three-clip footprints retain the owner's earlier physical-fit
confirmation. The USB edge alignment, added mounting holes and enlarged outline
are new. Inspect actual manufactured-board mating and enclosure access on delivery.
JLC's public upload parser recognized four layers and a 334 × 172 mm board on
2026-09-19. Its detailed Gerber viewer requires sign-in; order-specific engineering
DFM and production-file approval remain order steps. Independent local CAM parsing
and visual inspection are recorded separately in the release evidence. No parts
or boards have been purchased by this work.

Production approval requires recorded fault/isolation, recovery, USB, regulator,
thermal and mechanical results, plus the installation/load specification deferred
by the owner. Keep that separate from prototype fabrication approval.

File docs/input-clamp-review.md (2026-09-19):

# Input clamp review — prototype scope, 2026-09-19

The fitted clamps provide a plausible prototype protection network. Their
datasheet pulse ratings do **not** qualify an unspecified battery feeder, an
energized short circuit, or arbitrary inductive loads. This review permits
controlled prototype evaluation; installation transient qualification remains
a production gate.

## Coordination

| Device | Published point at 25 °C | Review consequence |
|---|---|---|
| D3, Littelfuse SMCJ24CA, raw input | 24 V stand-off; 26.7–29.5 V breakdown; 38.9 V clamp at 38.6 A | Below the 50 V input capacitor and 60 V reverse-FET ratings at this test point. The 55.56 A controller current-limit corner exceeds that specified clamp current: 38.9 V is not a bound for that event. |
| D6, Littelfuse SMCJ16A, protected bus | 16 V stand-off; 17.8–19.7 V breakdown; 26 V clamp at 57.7 A | Nominal coordination with the 28 V PROFET supply ceiling has only 2 V headroom. Temperature, pulse shape and trace inductance must be measured. |
| D7, STPS41L60CG-TR, GND to protected bus | Per diode: 0.60 V maximum at 20 A, 0.77 V at 40 A, at 25 °C under the stated pulse conditions | At 40 A, only 0.23 V remains before the TPS2492 OUT pin's −1 V absolute minimum. Attribute the entire current to one diode; tied anodes do not prove sharing. |

The TVS 1500 W rating uses a 10/1000 µs waveform, specified mounting copper,
and temperature derating. It is neither continuous power nor a universal joule
rating. The published 0.1%/K breakdown coefficient is typical; it cannot establish
a guaranteed hot clamp voltage. D6's forward conduction also cannot replace D7
as a sub-1 V negative clamp.

Sources: [Littelfuse SMCJ datasheet, February 2025](https://www.littelfuse.com/assetdocs/littelfuse_tvs_diode_smcj_datasheet.pdf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),
[ST STPS41L60C datasheet](https://www.st.com/resource/en/datasheet/stps41l60c.pdf),
[TI TPS2492 datasheet](https://www.ti.com/lit/gpn/TPS2492).

## Energy and test-fixture limits

For feeder inductance L and interrupted current I, initial stored energy is
L I²/2. If a source at Vs keeps feeding a clamp at Vc during decay, the ideal
clamp energy is L I²/2 × Vc/(Vc−Vs). Include this source contribution; using
only stored energy underestimates the input TVS burden.

For illustration, L = 10 µH, I = 5 A, Vs = 16 V and Vc = 38.9 V give 0.125 mJ
stored, approximately 0.212 mJ in D3, 194.5 W initial clamp power and 2.18 µs
ideal decay. These are fixture calculations, **not measured wiring or a clamp
guarantee**. A 40 A feeder stores 64 times as much energy at the same inductance;
it also exceeds D3's specified clamp-current point. Source output capacitors,
load capacitors, contact bounce and parasitic overshoot are absent from this
calculation. A bench supply's current-limit setting alone does not bound its
output-capacitor discharge current.

For the first powered checks, use a protected, current-limited laboratory source,
short paired leads, no external inductive loads and no deliberate energized
short. Begin with no branch fuses and a limit at or below 1 A; increase to at most
5 A only as needed after inspecting the rails. Document the fixture's output
capacitance, inductance and protection before fault testing. Deliberate transient
tests need an independently energy-limited fixture and a pulse-specific review.

Use differential probes at component pins, including U14 OUT relative to its
local GND. Initial measurement acceptance targets are raw input below 45 V,
protected bus below 27 V and OUT above −0.8 V; these are conservative test goals,
not additional component ratings. A scope limit is an acceptance check, not
instantaneous protective action. Stop increasing stress after any failed goal.
Keep Q3/Q4 mounting bases at or below 60 °C for the saved SOA screen; this is
not a 60 °C ambient rating. Verify the temperature measurement accounts for the
hidden mounting base rather than assuming the package top has the same temperature.

Increase startup, interruption and load-step currents in stages after recording
waveforms. Before any energized high-current short, review measured loop
inductance, source discharge current, controller response, individual gate
discharge and transient SOA. Before attaching motors/relays, review their stored
energy and local flyback/suppression. Reverse-polarity tests also start with a
limited source; the forward-path startup model does not test LM74800 behavior.

## Disposition

No clamp-value change is justified by the bounded initial bench work. The
voltage-coordination review is complete for prototype ordering. Full-current
fast-short survival, hot bus clamping, negative OUT overshoot, repetitive pulses
and installation fuse/cable/load coordination remain unqualified. These are
explicit limits of the prototype release, not findings erased by a CAD pass.

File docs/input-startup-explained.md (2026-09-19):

# What the 16 V / 40 A startup stall means

This is a **prediction from a tolerance-screening model**, not a measured board
failure. The owner resolved this requirement by accepting lower-load startup
latch-off; see the [prototype release](prototype-release.md).
The saved circuit still uses R17 = 8.25 kΩ, R18 = 1 kΩ and C18 = 10 nF.

## How the stall happens

The input pass MOSFETs act as a controlled resistance while the output rises.
They must carry the connected BYPASS loads as well as charge the bus and load
capacitors. During this interval they can dissipate far more power than when
fully on. TPS2492 deliberately restricts that dissipation.

For the illustrative 40 A resistive load at 16 V, R = 16/40 = 0.4 Ω.
At an intermediate output voltage V, load current is V/0.4 and the MOSFETs
drop 16 − V volts. Their required power, before capacitor charging, is therefore
**P = V × (16 − V) / 0.4**. It peaks at **160 W**, at 8 V output and 20 A.
That is heat in the pass stage during startup, not the load's 640 W running power.

The nominal programmed limit is 216.2 W, but the low tolerance screen is
137.9 W. At this setting the rising output reaches an equilibrium near
**5.03 V and 12.57 A**: all available current supplies the resistor and none
remains to raise the output. The later mathematical root at 10.97 V does not
provide a path through the intervening power deficit. Extending the timeout
alone cannot solve this. Once limiting persists, the controller latches off;
actual gate dynamics and timing can interrupt the rise before that equilibrium.

The 137.9 W calculation includes REF voltage, divider/shunt tolerances, PROG
bias and the power engine's ±32% screen. TI's support clarification explicitly
uses ±32%; the electrical table establishes limits at specific test points.
This remains an engineering screen at our PROG setting, not a separately
guaranteed complete circuit model. The 44.55–55.56 A current-limit range is a
different constraint: it does not remove power limiting during startup.

Sources: [TPS2492 datasheet](https://www.ti.com/lit/gpn/TPS2492),
[TI power-limit accuracy clarification](https://e2e.ti.com/support/power-management-group/power-management/f/power-management-forum/1074250/tps2492-how-precise-is-the-constant-power-engine-what-measurement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).

## Concrete setting comparisons — none selected or approved

These comparisons use the same **illustrative** 16 V, 0.4 Ω load and 1,000 µF
total bus/load capacitance. The capacitance is not an owner-supplied load
specification. Each candidate changes only two fitted values in the existing
footprints, but electrical approval is still required.

| R17 / C18 | Low power screen | Ideal charge time | Minimum timer | High power × maximum timer |
|---|---:|---:|---:|---:|
| 8.25 kΩ / 10 nF, currently fitted | 137.9 W | Stalls | 1.029 ms | 0.769 J |
| 6.81 kΩ / 100 nF | 163.7 W | 7.784 ms | 10.292 ms | 9.093 J |
| 6.19 kΩ / 47 nF | 178.0 W | 3.341 ms | 4.837 ms | 4.638 J |
| 5.62 kΩ / 33 nF | 193.6 W | 2.382 ms | 3.396 ms | 3.533 J |
| 5.11 kΩ / 27 nF | 209.9 W | 1.926 ms | 2.779 ms | 3.129 J |

The smallest power increase has little margin over 160 W and needs the longest
timeout. A larger increase can reduce total limited fault energy, while raising
peak stress. **The final column is not a total fault-energy bound**: TIMER runs
while limiting, and gate-limited intervals and switching overshoot are omitted.
None of these rows proves single-device hot SOA, fast-short survival or startup
with an arbitrary electronic load. Parallel sharing is not credited.

Real electronics can draw almost constant power above their undervoltage
threshold; motors can draw starting or stalled current. Neither is equivalent
to the resistor example. Those loads and their capacitance need a bounded
startup envelope and prototype validation.

## Owner decision — 2026-09-19

The owner accepted startup latch-off at a lower load while keeping the 40 A
continuous target. Successful full-40-A BYPASS startup is not required. The selected validation target is a 20 A resistor plus a 2 A auxiliary-current
allowance, or a 5 A total active-current bound, with at most 220 µF actual
bus/load capacitance. Analytical and transient sensitivity checks now support
controlled prototype fabrication. Hardware startup/fault tests remain required.

Run `python3 tools/input_stage_analysis.py --check` to check the saved numerical
evidence, or add `--plot` to export the explanatory PNG/PDF under `out/review/`.
The integrator is cross-checked against independent unloaded and resistive-load
closed forms. CAD verification now checks calculation freshness too; a passing
freshness check is not a hardware test. See `tools/input_stage_transient.py`
for the separate gate-dynamics sensitivity study.

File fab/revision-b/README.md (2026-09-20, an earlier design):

# Withdrawn revision-B fabrication package

**Do not order this ZIP or its Gerbers.** The release was withdrawn on 2026-09-19
after the owner required a shorted output to be isolated while healthy outputs
remain operating in AUTO and BYPASS. The saved revision-B circuit does not
establish that behavior, and layout corrections remain open.

The package is retained unchanged for historical traceability. See
[release status](../../docs/release-status.json) and
[channel isolation review](../../docs/channel-isolation-review.md).

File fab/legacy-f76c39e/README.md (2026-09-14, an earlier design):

# Obsolete fabrication artifacts — do not order

These files were previously at the top of `fab/` and are preserved unchanged for
historical reference. They do not match the current reviewed parts, connectors,
fabrication constraints or fuse labels. The embedded fabrication notes are stale.

No current PCB order is approved. See [the critical review](../../docs/critical-review.md).

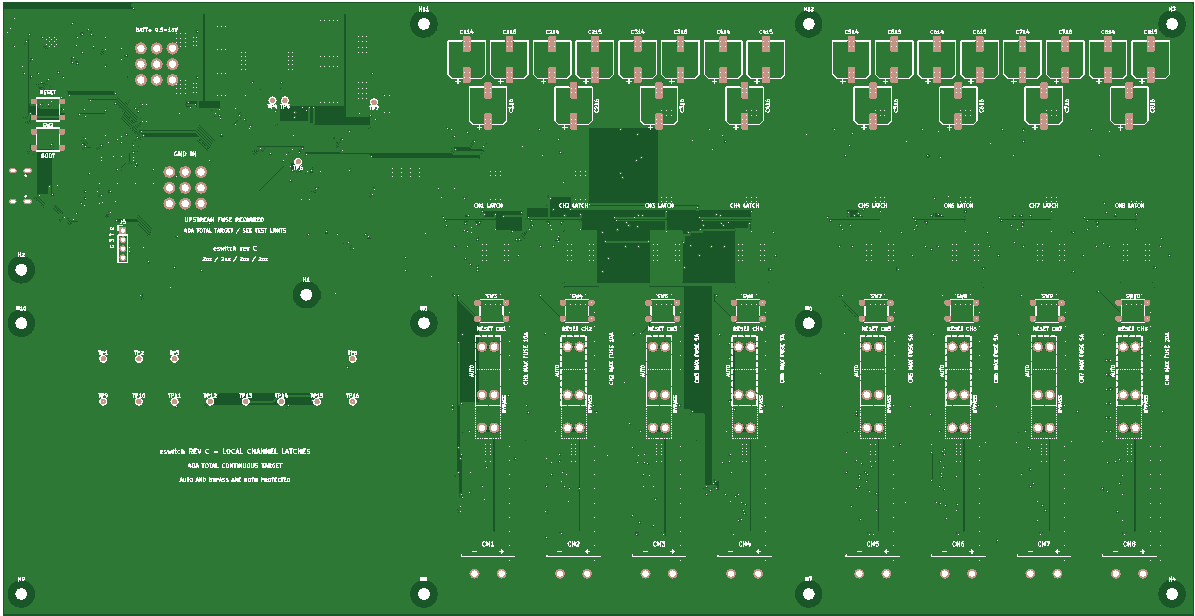
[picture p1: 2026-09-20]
fab/revision-c/jlc-preview-top.png

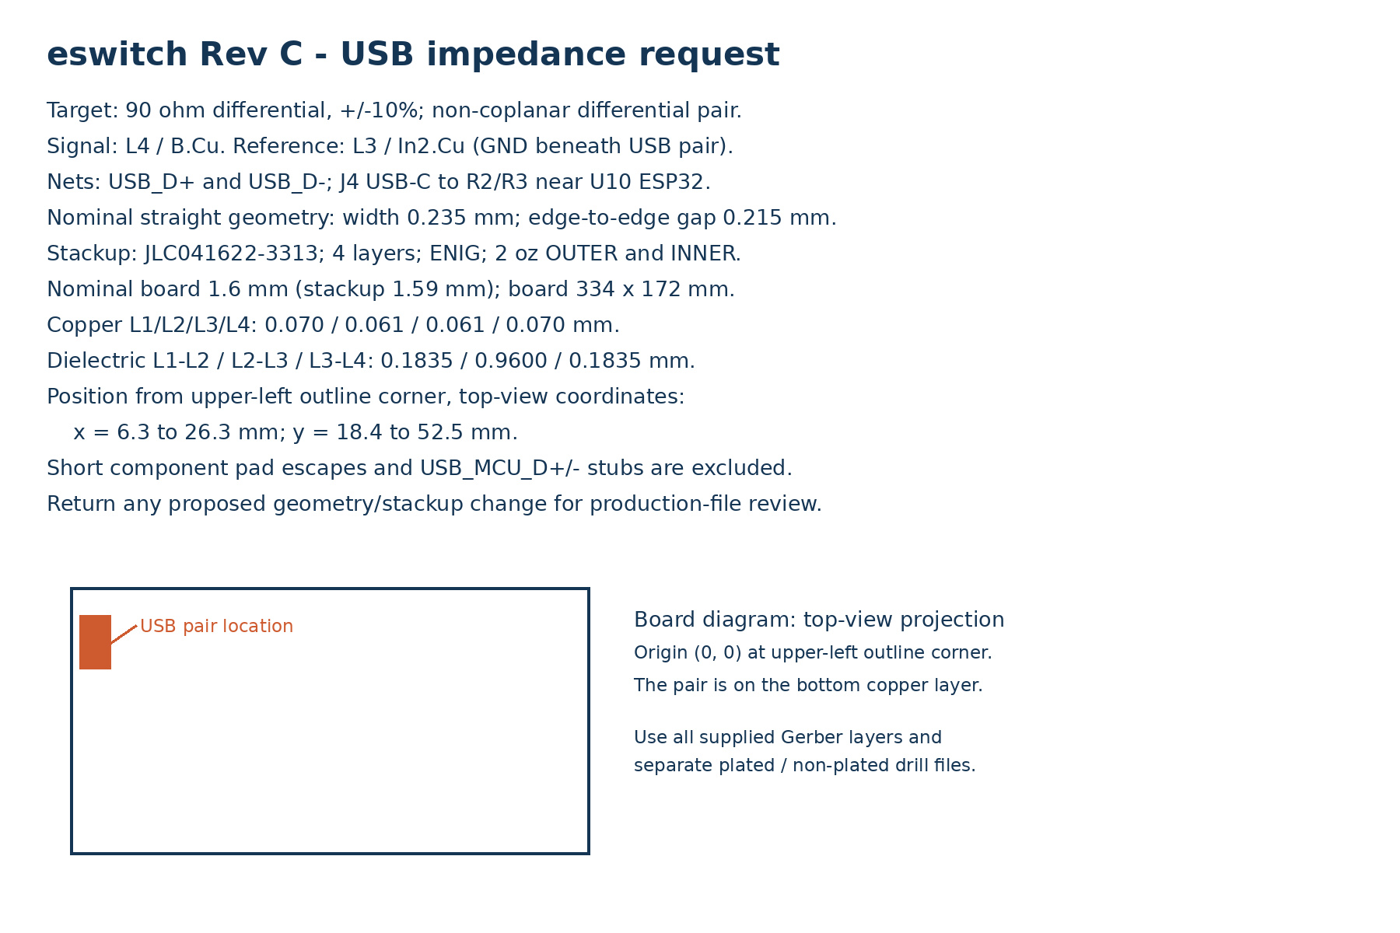
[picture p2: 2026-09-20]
fab/revision-c/gerbers/USB-impedance-request.jpg

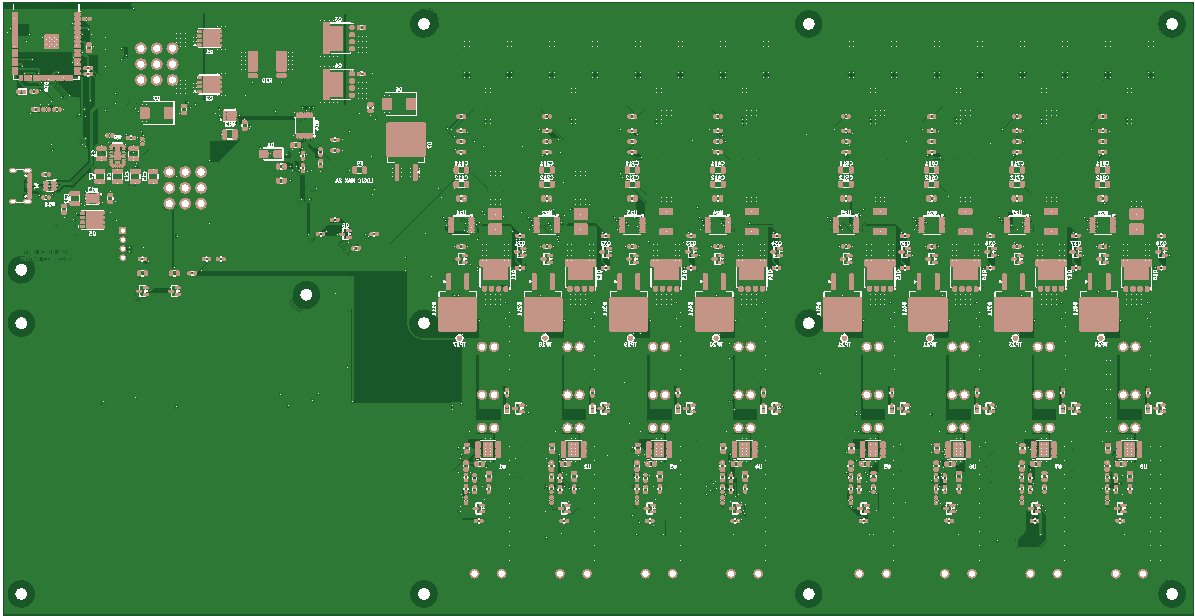
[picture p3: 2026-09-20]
fab/revision-c/jlc-preview-bottom.png

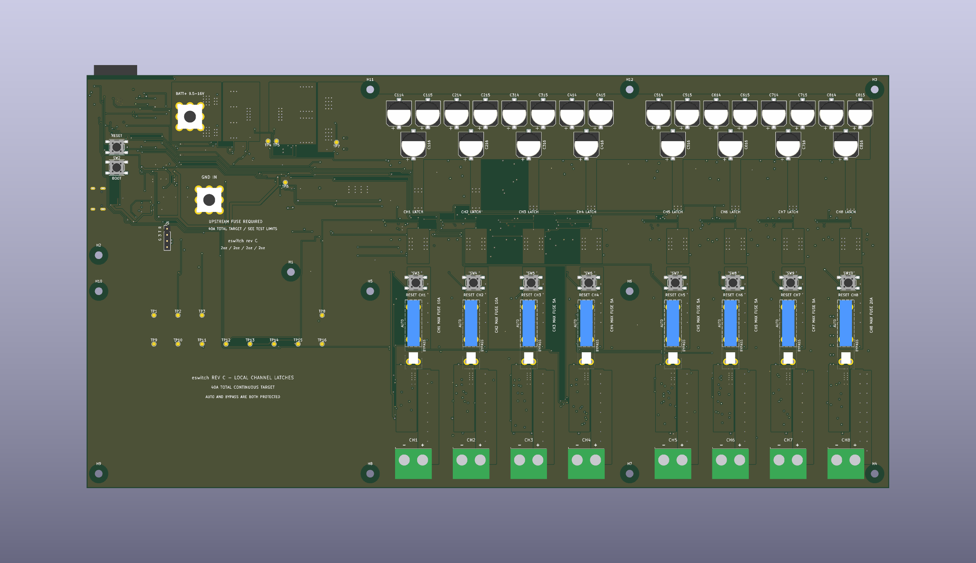
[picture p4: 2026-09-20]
fab/revision-c/board-top.png

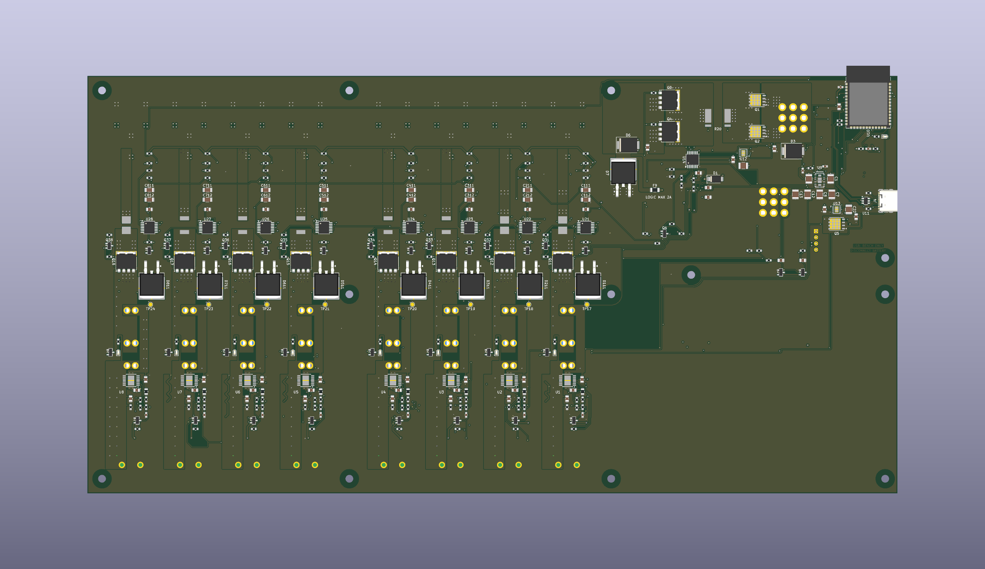
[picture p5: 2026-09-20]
fab/revision-c/board-bottom.png

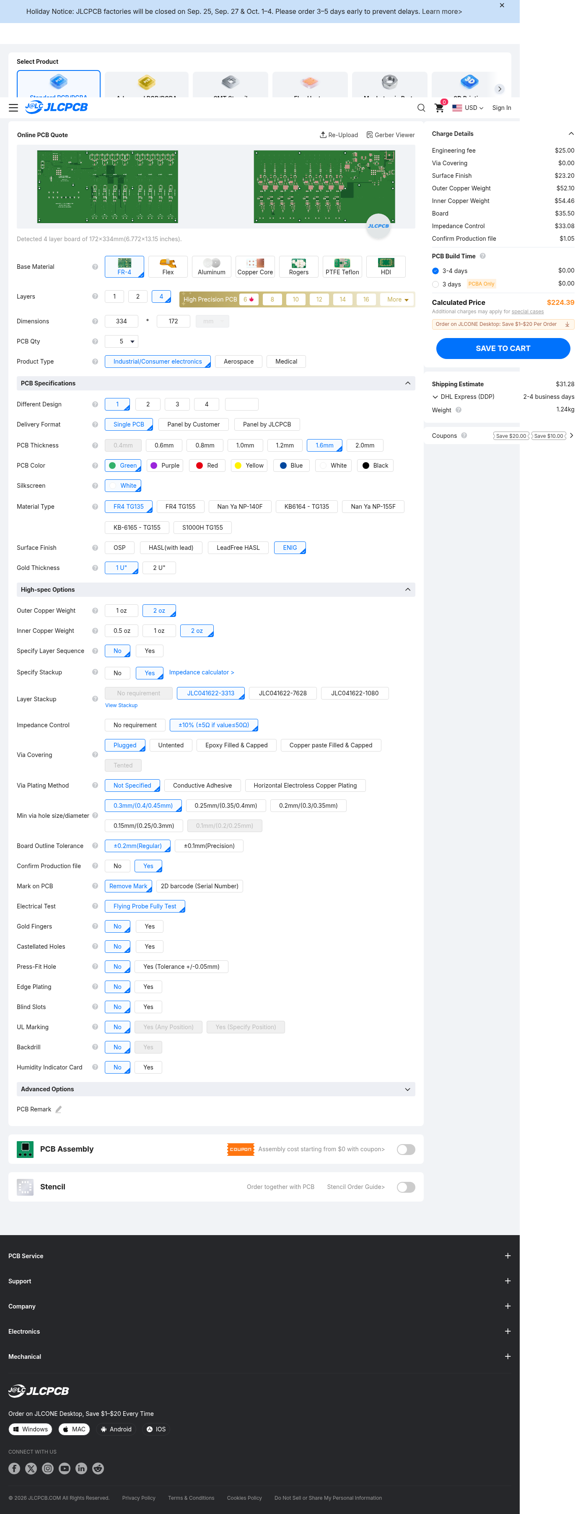
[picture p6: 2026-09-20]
fab/revision-c/jlc-configured-quote.png

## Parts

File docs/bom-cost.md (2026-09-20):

# Revision C BOM cost — 2026-09-19

The current one-board BOM is **US$318.40**, including the eight output fuse
inserts and twelve M3 standoffs. Board components account for $309.66;
fuse inserts and standoffs account for $8.74.

Buying a few additional pieces to reach cheaper price breaks reduces the
one-board purchasing subtotal to **$299.30**, including those spares.
The installed BOM quantities remain for exactly one board.

For the planned **three-board build**, buying exactly three sets together costs
**$800.31 total**, or **$266.77 per board**, using the
applicable quantity breaks. This comparison does not change the one-board import
BOM. See the [three-board cost breakdown](../fab/digikey/cost-three-board-build.csv).

- [Exact one-board BOM](../fab/digikey/eswitch-digikey-bom.csv)
- [Price and quantity breakdown](../fab/digikey/cost-per-board.csv)
- [Optional cheaper cart, including explicitly listed spares](../fab/digikey/economical-one-board-cart.csv)
- [Dated price observations with individual DigiKey product links](digikey-prices.json)

These are displayed US distributor prices retrieved on the date above, with
cut tape or bulk packaging and price breaks applied to each line. They are an
estimate, not a reserved quote. PCB fabrication, assembly, solder/paste,
enclosure-specific screws and washers, shipping, taxes and tariffs are excluded.
See [release status](release-status.json) for fabrication readiness.

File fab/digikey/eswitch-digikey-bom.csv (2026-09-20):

Quantity | Manufacturer Part Number | Manufacturer | Customer Reference | Description
24 | 3557 | Keystone Electronics | F1, F2, F3, F4, F5, F6, F7, F8 | ATO holder clips; quantity counts individual clips, three per channel
2 | BTS70041EPPXUMA1 | Infineon | U1, U2 | BTS7004-1EPP / Package_SO:Infineon_PG-TSDSO-14-22
24 | RC0603FR-074K7L | YAGEO | R101, R102, R105, R201, R202, R205, R301, R302, R305, R401, R402, R405, R501, R502, R505, R601, R602, R605, R701, R702, R705, R801, R802, R805 | 4.7k / Resistor_SMD:R_0603_1608Metric
8 | RC0805FR-0747RL | YAGEO | R103, R203, R303, R403, R503, R603, R703, R803 | 47R / Resistor_SMD:R_0805_2012Metric
2 | RC0603FR-072K2L | YAGEO | R104, R204 | 2.2k 1% / Resistor_SMD:R_0603_1608Metric
8 | CL10C221JB8NFNC | Samsung Electro-Mechanics | C103, C203, C303, C403, C503, C603, C703, C803 | 220pF 50V / Capacitor_SMD:C_0603_1608Metric
26 | BAT54S-QR | Nexperia | D101, D201, D301, D401, D501, D601, D701, D801, D8, D9, D112, D103, D212, D203, D312, D303, D412, D403, D512, D503, D612, D603, D712, D703, D812, D803 | BAT54S / Package_TO_SOT_SMD:SOT-23
21 | CL21B104KBCNNNC | Samsung Electro-Mechanics | C101, C201, C301, C401, C501, C601, C701, C801, C15, C16, C19, C20, C21, C113, C213, C313, C413, C513, C613, C713, C813 | 100nF 50V / Capacitor_SMD:C_0805_2012Metric
28 | RC0603FR-0747KL | YAGEO | R106, R206, R306, R406, R506, R606, R706, R806, R108, R208, R308, R408, R508, R608, R708, R808, R22, R23, R25, R28, R114, R214, R314, R414, R514, R614, R714, R814 | 47k / Resistor_SMD:R_0603_1608Metric
10 | CL21B103KBANNNC | Samsung Electro-Mechanics | C102, C202, C302, C402, C502, C602, C702, C802, C23, C24 | 10nF 50V / Capacitor_SMD:C_0805_2012Metric
20 | RC0603FR-0710KL | YAGEO | R107, R207, R307, R407, R507, R607, R707, R807, R5, R6, R21, R24, R115, R215, R315, R415, R515, R615, R715, R815 | 10k / Resistor_SMD:R_0603_1608Metric
8 | 150060GS75000 | Wurth Elektronik | D102, D202, D302, D402, D502, D602, D702, D802 | GREEN / LED_SMD:LED_0603_1608Metric
5 | BTS70081EPRXUMA1 | Infineon | U3, U4, U5, U6, U7 | BTS7008-1EPR / Package_SO:Infineon_PG-TSDSO-14-22
5 | RC0603FR-073K3L | YAGEO | R304, R404, R504, R604, R704 | 3.3k 1% / Resistor_SMD:R_0603_1608Metric
1 | BTS70021EPPXUMA1 | Infineon | U8 | BTS7002-1EPP / Package_SO:Infineon_PG-TSDSO-14-22
1 | RC0603FR-071K2L | YAGEO | R804 | 1.2k 1% / Resistor_SMD:R_0603_1608Metric
1 | ESP32-S3-WROOM-1-N8 | Espressif | U10 | ESP32-S3-WROOM-1-N8 / eswitch:ESP32-S3-WROOM-1_Edge
1 | CC0805KKX5R6BB106 | YAGEO | C9 | 10uF 10V / Capacitor_SMD:C_0805_2012Metric
2 | CC0603JRX7R9BB104 | YAGEO | C10, C3 | 100nF, 100nF 50V / Capacitor_SMD:C_0603_1608Metric
2 | CC0603KRX7R7BB105 | YAGEO | C11, C14 | 1uF / Capacitor_SMD:C_0603_1608Metric
10 | PTS645SM43SMTR92 LFS | C&K | SW1, SW2, SW3, SW4, SW5, SW6, SW7, SW8, SW9, SW10 | RESET, BOOT, RESET CH1, RESET CH2, RESET CH3, RESET CH4, RESET CH5, RESET CH6, RESET CH7, RESET CH8 / Button_Switch_SMD:SW_SPST_PTS645Sx43SMTR92
1 | RC0603FR-071KL | YAGEO | R9 | 1k / Resistor_SMD:R_0603_1608Metric
1 | 150060BS75000 | Wurth Elektronik | D5 | BLUE / LED_SMD:LED_0603_1608Metric
1 | USB4105-GF-A | GCT | J4 | USB-C / eswitch:USB4105_NPTH_0p2
1 | SRV05-4HTG-D | Littelfuse | U11 | SRV05-4HTG-D / Package_TO_SOT_SMD:SOT-23-6
2 | ERJ-3EKF5101V | Panasonic | R7, R8 | 5.1k / Resistor_SMD:R_0603_1608Metric
1 | 61300411121 | Wurth Elektronik | J5 | UART / Connector_PinHeader_2.54mm:PinHeader_1x04_P2.54mm_Vertical
1 | 0466002.NR | Littelfuse | F9 | 2A 1206 / Fuse:Fuse_1206_3216Metric
1 | B360A-13-F | Diodes Incorporated | D1 | B360A / Diode_SMD:D_SMA
1 | SMCJ24CA | Littelfuse | D3 | SMCJ24CA / Diode_SMD:D_SMC
4 | GRM32ER71H475KA88L | Murata | C1, C2, C17, C22 | 4.7uF 50V / Capacitor_SMD:C_1210_3225Metric
1 | TPSM63603V3RDHR | Texas Instruments | U9 | TPSM63603V3 / eswitch:TI_RDH0030A_TPSM63603
1 | RC0603FR-0716K5L | YAGEO | R1 | 16.5k 1% / Resistor_SMD:R_0603_1608Metric
4 | GCM32ER70J476KE19L | Murata | C7, C8, C12, C13 | 47uF 6.3V X7R / Capacitor_SMD:C_1210_3225Metric
8 | 691218410002 | Wurth Elektronik | J1, J6, J7, J8, J9, J10, J11, J12 | 691218410002 / eswitch:TerminalBlock_1x02_P7.62mm_Wuerth_2184
2 | 74650195 | Wurth Elektronik | J2, J3 | BATT+ 9.5-16V, GND IN / eswitch:ScrewTerminal_Wuerth_74650195_M5
2 | ERJ-3EKF22R0V | Panasonic Industry | R10, R11 | 22R / Resistor_SMD:R_0603_1608Metric
3 | BSC016N06NSATMA1 | Infineon | Q1, Q2, Q5 | BSC016N06NS / Package_SON:Infineon_PG-TDSON-8_6.15x5.15mm
2 | LM74800QDRRRQ1 | Texas Instruments | U12, U13 | LM74800-Q1 / Package_SON:WSON-12-1EP_3x3mm_P0.5mm_EP1.5x2.5mm
10 | PSMN1R8-80SSEJ | Nexperia | Q3, Q4, Q11, Q12, Q13, Q14, Q15, Q16, Q17, Q18 | PSMN1R8-80SSE / Package_TO_SOT_SMD:LFPAK88
9 | TPS2492PWR | Texas Instruments | U14, U21, U22, U23, U24, U25, U26, U27, U28 | TPS2492 (LATCH), TPS2492 (CHANNEL LATCH) / Package_SO:TSSOP-14_4.4x5mm_P0.65mm
1 | CSS4J-4026R-L500F | Bourns | R20 | 0.5mR 1% 5W / eswitch:Bourns_CSS4J_4026
2 | RT0603BRD07115KL | YAGEO | R12, R26 | 115k 0.1% / Resistor_SMD:R_0603_1608Metric
3 | RT0603BRD0710KL | YAGEO | R13, R15, R27 | 10k 0.1% / Resistor_SMD:R_0603_1608Metric
1 | RT0603BRD0756K2L | YAGEO | R14 | 56.2k 0.1% / Resistor_SMD:R_0603_1608Metric
18 | RC0603FR-0710RL | YAGEO | R16, R19, R116, R117, R216, R217, R316, R317, R416, R417, R516, R517, R616, R617, R716, R717, R816, R817 | 10R / Resistor_SMD:R_0603_1608Metric
1 | RT0603BRD078K25L | YAGEO | R17 | 8.25k 0.1% / Resistor_SMD:R_0603_1608Metric
9 | RT0603BRD071KL | YAGEO | R18, R113, R213, R313, R413, R513, R613, R713, R813 | 1k 0.1% / Resistor_SMD:R_0603_1608Metric
3 | C0805C123J5GACTU | KEMET | C18, C25, C28 | 12nF 50V C0G 5% / Capacitor_SMD:C_0805_2012Metric
1 | SMCJ16A | Littelfuse | D6 | SMCJ16A / Diode_SMD:D_SMC
9 | STPS41L60CG-TR | STMicroelectronics | D7, D111, D211, D311, D411, D511, D611, D711, D811 | STPS41L60CG / Package_TO_SOT_SMD:TO-263-2
8 | CL21B473KBCNNNC | Samsung Electro-Mechanics | C104, C204, C304, C404, C504, C604, C704, C804 | 47nF 50V / Capacitor_SMD:C_0805_2012Metric
1 | MMBT3906LT1G | onsemi | Q6 | MMBT3906LT1G / Package_TO_SOT_SMD:SOT-23
24 | 35SVPF120M | Panasonic Industry | C114, C115, C116, C214, C215, C216, C314, C315, C316, C414, C415, C416, C514, C515, C516, C614, C615, C616, C714, C715, C716, C814, C815, C816 | 120uF 35V polymer / Capacitor_SMD:CP_Elec_10x12.6
2 | WSLP25124L000FEA | Vishay Dale | R120, R220 | 4mR 1% 3W / eswitch:WSLP2512_2m
8 | RC0603FR-07100RL | YAGEO | R111, R211, R311, R411, R511, R611, R711, R811 | 100R / Resistor_SMD:R_0603_1608Metric
2 | RT0603BRD074K7L | YAGEO | R112, R212 | 4.7k 0.1% / Resistor_SMD:R_0603_1608Metric
8 | FMMT720TA | Diodes Incorporated | Q31, Q32, Q33, Q34, Q35, Q36, Q37, Q38 | FMMT720TA / Package_TO_SOT_SMD:SOT-23
16 | C1206C104J5JACAUTO | KEMET | C111, C112, C211, C212, C311, C312, C411, C412, C511, C512, C611, C612, C711, C712, C811, C812 | 100nF 50V U2J 5% / Capacitor_SMD:C_1206_3216Metric
5 | WSLP25128L000FEA | Vishay Dale | R320, R420, R520, R620, R720 | 8mR 1% 3W / eswitch:WSLP2512_8m
5 | RG1608P-222-B-T5 | Susumu | R312, R412, R512, R612, R712 | 2.2k 0.1% / Resistor_SMD:R_0603_1608Metric
1 | WSLP25122L000FEA | Vishay Dale | R820 | 2mR 1% 3W / eswitch:WSLP2512_2m
1 | RT0603BRD077K5L | YAGEO | R812 | 7.5k 0.1% / Resistor_SMD:R_0603_1608Metric
5 | 0287005.PXCN | Littelfuse | F3-F7 inserts | 5 A ATO fuse; ambient derating applies
2 | 0287010.PXCN | Littelfuse | F1-F2 inserts | 10 A ATO fuse; ambient derating applies
1 | 0287020.PXCN | Littelfuse | F8 insert | 20 A ATO fuse; NOT 20 A continuous at all ambients
12 | R30-1001002 | Harwin | H1-H12 standoffs | M3 x 10 mm; verify enclosure clearance

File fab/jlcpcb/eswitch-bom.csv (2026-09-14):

Comment | Designator | Footprint | LCSC Part #
GRM32ER71H475KA88L | C1,C2 | 1210
CL10B104KB8NNNC | C3 | 0603 | C14663
CL10B104KB8NNNC | C4 | 0603 | C14663
CL10B273KB8NNNC | C5 | 0603
CL10C151JB8NNNC | C6 | 0603
GRM32ER71A226KE20L | C7,C8 | 1210
CL21A106KPFNNNE | C9 | 0805 | C15850
CL10B104KB8NNNC | C10 | 0603 | C14663
CL10B105KO8NNNC | C11 | 0603 | C15849
CL21B104KBCNNNC | C101,C201,C301,C401,C501,C601,C701,C801 | 0805 | C49678
CL21B103KBANNNC | C102,C202,C302,C402,C502,C602,C702,C802 | 0805
CL10C221JB8NNNC | C103,C203,C303,C403,C503,C603,C703,C803 | 0603 | C1653
B360-13-F | D1,D2,D4 | SMA
SMBJ26A | D3 | SMB
150060BS75000 | D5 | LED_0603 | C72041
BAT54S,215 | D101,D201,D301,D401,D501,D601,D701,D801 | SOT-23 | C47547
150060GS75000 | D102,D202,D302,D402,D502,D602,D702,D802 | LED_0603 | C72043
0466002.NR | F9 | 1206
USB4105-GF-A | J4 | USB_C_Receptacle_GCT_USB4105-xx-A_16P_TopMnt_Horizontal
SRP7028A-100M | L1 | L_Bourns_SRP7028A_7.3x6.6mm
RC0603FR-07200KL | R1 | 0603 | C25811
RC0603FR-0731K6L | R2 | 0603
RC0603FR-0710K2L | R3 | 0603
RC0603FR-073K9L | R4 | 0603 | C23018
RC0603FR-0710KL | R5,R6 | 0603 | C25804
RC0603FR-075K1L | R7,R8 | 0603 | C23186
RC0603FR-071KL | R9 | 0603 | C21190
RC0603FR-074K7L | R101,R102,R105,R201,R202,R205,R301,R302,R305,R401,R402,R405,R501,R502,R505,R601,R602,R605,R701,R702,R705,R801,R802,R805 | 0603 | C23162
RC0805FR-0747RL | R103,R203,R303,R403,R503,R603,R703,R803 | 0805
RC0603FR-072K2L | R104,R204 | 0603
RC0603FR-0747KL | R106,R206,R306,R406,R506,R606,R706,R806 | 0603 | C25819
RC0603FR-072K2L | R107,R207,R307,R407,R507,R607,R707,R807 | 0603 | C4190
RC0603FR-073K3L | R304,R404,R504,R604,R704 | 0603
RC0603FR-071K2L | R804 | 0603 | C22765
PTS645SM43SMTR92 | SW1 | SW_SPST_PTS645Sx43SMTR92
PTS645SM43SMTR92 | SW2 | SW_SPST_PTS645Sx43SMTR92
BTS70041EPPXUMA1 | U1,U2 | Infineon_PG-TSDSO-14-22
BTS70081EPRXUMA1 | U3,U4,U5,U6,U7 | Infineon_PG-TSDSO-14-22
BTS70021EPPXUMA1 | U8 | Infineon_PG-TSDSO-14-22
TPS54360BDDAR | U9 | TI_SO-PowerPAD-8_ThermalVias
ESP32-S3-WROOM-1-N8 | U10 | ESP32-S3-WROOM-1 | C2913202
USBLC6-2SC6 | U11 | SOT-23-6 | C7519

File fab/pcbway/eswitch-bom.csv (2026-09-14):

Item # | Designator | Qty | Manufacturer | Mfg Part # | Description / Value | Package/Footprint | Type | Your Instructions / Notes
1 | C1,C2 | 2 | Murata | GRM32ER71H475KA88L | 4.7uF 50V | 1210 | SMD
2 | C3 | 1 | Samsung Electro-Mechanics | CL10B104KB8NNNC | 100nF 50V | 0603 | SMD
3 | C4 | 1 | Samsung Electro-Mechanics | CL10B104KB8NNNC | 100nF 25V | 0603 | SMD
4 | C5 | 1 | Samsung Electro-Mechanics | CL10B273KB8NNNC | 27nF | 0603 | SMD
5 | C6 | 1 | Samsung Electro-Mechanics | CL10C151JB8NNNC | 150pF | 0603 | SMD
6 | C7,C8 | 2 | Murata | GRM32ER71A226KE20L | 22uF 10V | 1210 | SMD
7 | C9 | 1 | Samsung Electro-Mechanics | CL21A106KPFNNNE | 10uF 10V | 0805 | SMD
8 | C10 | 1 | Samsung Electro-Mechanics | CL10B104KB8NNNC | 100nF | 0603 | SMD
9 | C11 | 1 | Samsung Electro-Mechanics | CL10B105KO8NNNC | 1uF | 0603 | SMD
10 | C101,C201,C301,C401,C501,C601,C701,C801 | 8 | Samsung Electro-Mechanics | CL21B104KBCNNNC | 100nF 50V | 0805 | SMD | CVS
11 | C102,C202,C302,C402,C502,C602,C702,C802 | 8 | Samsung Electro-Mechanics | CL21B103KBANNNC | 10nF 50V | 0805 | SMD | COUT
12 | C103,C203,C303,C403,C503,C603,C703,C803 | 8 | Samsung Electro-Mechanics | CL10C221JB8NNNC | 220pF 50V | 0603 | SMD | CSENSE
13 | D1,D2,D4 | 3 | Diodes Incorporated | B360-13-F | SS36 | SMA | SMD | 12V -> VIN,USB -> VIN,catch diode
14 | D3 | 1 | Littelfuse | SMBJ26A | SMBJ26A | SMB | SMD | bus TVS
15 | D5 | 1 | Wurth Elektronik | 150060BS75000 | BLUE | LED_0603 | SMD | status LED IO41
16 | D101,D201,D301,D401,D501,D601,D701,D801 | 8 | Nexperia | BAT54S,215 | BAT54S | SOT-23 | SMD | ADC clamp
17 | D102,D202,D302,D402,D502,D602,D702,D802 | 8 | Wurth Elektronik | 150060GS75000 | GREEN | LED_0603 | SMD | load ON indicator
18 | F1,F2 | 2 | Keystone Electronics | 3557 | ATO 10A | Fuseholder_ATO_3pos_Keystone_3557 | Through-hole | 3 clips per position; CH1 10 A; AUTO: fuse in COM-SW; BYPASS: fuse in COM-LOAD,3 clips per position; CH2 10 A; AUTO: fuse in COM-SW; BYPASS: fuse in COM-LOAD
19 | F3,F4,F5,F6,F7 | 5 | Keystone Electronics | 3557 | ATO 5A | Fuseholder_ATO_3pos_Keystone_3557 | Through-hole | 3 clips per position; CH3 5 A; AUTO: fuse in COM-SW; BYPASS: fuse in COM-LOAD,3 clips per position; CH4 5 A; AUTO: fuse in COM-SW; BYPASS: fuse in COM-LOAD,3 clips per position; CH5 5 A; AUTO: fuse in COM-SW; BYPASS: fuse in COM-LOAD,3 clips per position; CH6 5 A; AUTO: fuse in COM-SW; BYPASS: fuse in COM-LOAD,3 clips per position; CH7 5 A; AUTO: fuse in COM-SW; BYPASS: fuse in COM-LOAD
20 | F8 | 1 | Keystone Electronics | 3557 | ATO 20A | Fuseholder_ATO_3pos_Keystone_3557 | Through-hole | 3 clips per position; CH8 20 A; AUTO: fuse in COM-SW; BYPASS: fuse in COM-LOAD
21 | F9 | 1 | Littelfuse | 0466002.NR | 2A 1206 | 1206 | SMD | logic supply fuse
22 | H1,H2,H3,H4 | 4 |  |  | M3 | MountingHole_3.2mm_M3 | Through-hole
23 | J1 | 1 | Wurth Elektronik | 691311400116 | Wuerth 691311400116 | TerminalBlock_1x16_P7.62mm_Wuerth_3114 | Through-hole | odd pins = GND, even pins = LOAD+
24 | J2 | 1 | Keystone Electronics | 8196 | +12V IN | ScrewTerminal_Keystone_8196_10-32 | Through-hole
25 | J3 | 1 | Keystone Electronics | 8196 | GND IN | ScrewTerminal_Keystone_8196_10-32 | Through-hole
26 | J4 | 1 | GCT | USB4105-GF-A | USB-C | USB_C_Receptacle_GCT_USB4105-xx-A_16P_TopMnt_Horizontal | SMD
27 | J5 | 1 | Wurth Elektronik | 61300411121 | UART | PinHeader_1x04_P2.54mm_Vertical | Through-hole | GND 3V3 TX RX
28 | L1 | 1 | Bourns | SRP7028A-100M | 10uH 4A | L_Bourns_SRP7028A_7.3x6.6mm | SMD
29 | R1 | 1 | YAGEO | RC0603FR-07200KL | 200k 1% | 0603 | SMD | fsw 500 kHz
30 | R2 | 1 | YAGEO | RC0603FR-0731K6L | 31.6k 1% | 0603 | SMD
31 | R3 | 1 | YAGEO | RC0603FR-0710K2L | 10.2k 1% | 0603 | SMD
32 | R4 | 1 | YAGEO | RC0603FR-073K9L | 3.9k | 0603 | SMD
33 | R5,R6 | 2 | YAGEO | RC0603FR-0710KL | 10k | 0603 | SMD
34 | R7,R8 | 2 | YAGEO | RC0603FR-075K1L | 5.1k | 0603 | SMD
35 | R9 | 1 | YAGEO | RC0603FR-071KL | 1k | 0603 | SMD
36 | R101,R102,R105,R201,R202,R205,R301,R302,R305,R401,R402,R405,R501,R502,R505,R601,R602,R605,R701,R702,R705,R801,R802,R805 | 24 | YAGEO | RC0603FR-074K7L | 4.7k | 0603 | SMD | RADC,RDEN,RIN
37 | R103,R203,R303,R403,R503,R603,R703,R803 | 8 | YAGEO | RC0805FR-0747RL | 47R | 0805 | SMD | RGND (ReverseON)
38 | R104,R204 | 2 | YAGEO | RC0603FR-072K2L | 2.2k 1% | 0603 | SMD | RSENSE
39 | R106,R206,R306,R406,R506,R606,R706,R806 | 8 | YAGEO | RC0603FR-0747KL | 47k | 0603 | SMD | RPD
40 | R107,R207,R307,R407,R507,R607,R707,R807 | 8 | YAGEO | RC0603FR-072K2L | 2.2k | 0603 | SMD | RLED
41 | R304,R404,R504,R604,R704 | 5 | YAGEO | RC0603FR-073K3L | 3.3k 1% | 0603 | SMD | RSENSE
42 | R804 | 1 | YAGEO | RC0603FR-071K2L | 1.2k 1% | 0603 | SMD | RSENSE
43 | SW1 | 1 | C&K | PTS645SM43SMTR92 | RESET | SW_SPST_PTS645Sx43SMTR92 | SMD
44 | SW2 | 1 | C&K | PTS645SM43SMTR92 | BOOT | SW_SPST_PTS645Sx43SMTR92 | SMD
45 | U1,U2 | 2 | Infineon | BTS70041EPPXUMA1 | BTS7004-1EPP | Infineon_PG-TSDSO-14-22 | SMD | CH1 10 A,CH2 10 A
46 | U3,U4,U5,U6,U7 | 5 | Infineon | BTS70081EPRXUMA1 | BTS7008-1EPP | Infineon_PG-TSDSO-14-22 | SMD | CH3 5 A,CH4 5 A,CH5 5 A,CH6 5 A,CH7 5 A
47 | U8 | 1 | Infineon | BTS70021EPPXUMA1 | BTS7002-1EPP | Infineon_PG-TSDSO-14-22 | SMD | CH8 20 A
48 | U9 | 1 | Texas Instruments | TPS54360BDDAR | TPS54360B | TI_SO-PowerPAD-8_ThermalVias | SMD
49 | U10 | 1 | Espressif | ESP32-S3-WROOM-1-N8 | ESP32-S3-WROOM-1-N8 | ESP32-S3-WROOM-1 | SMD
50 | U11 | 1 | STMicroelectronics | USBLC6-2SC6 | USBLC6-2SC6 | SOT-23-6 | SMD

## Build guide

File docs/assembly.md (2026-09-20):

# Three-board manual assembly

The current circuit is revision C. Use its matching Gerbers and BOM only; check
[release status](release-status.json) before fabrication. Assemble one board first.

Agreed method: solder paste with hot air or a hot plate is available. Exposed-pad
devices remain on the BOM; this is not an iron-only design. Procurement is through
DigiKey, with enough stock for three complete boards at the recorded check date.

`just bom` produces a **per-board** purchasing CSV and an inventory evidence CSV in
`fab/digikey/`. Every quantity is for **one complete module**, without a batch
multiplier. The purchaser chooses how many modules to order. Quantities are
minimum build quantities, **without spares**. For
small passives, ordering a few extra is sensible. No purchase has been made.
The dated audit is not an inventory reservation; refresh it at checkout and after
any circuit changes. The BOM describes the revision-C circuit;
installation hardware is listed separately below.

## Assembly sequence

1. Start with one board. Inspect the bare PCB and check resistance between supply
   and ground before applying power. Keep the other two unassembled until bring-up.
2. Populate the bottom-side SMD with controlled paste volume. Reflow the exposed
   pads on U1–U9, the MOSFET mounting bases and the ESP32 module ground pad; an edge fillet alone does not prove
   a sound underside joint. Follow the component moisture/reflow requirements and
   the paste manufacturer's measured temperature profile. Hot-plate dial temperature
   is not the solder-joint temperature. Support the overhanging ESP32 antenna.
3. Fit the 24 top-side 35SVPF120M reservoir capacitors with correct polarity. Their
   F12 case is 12.6 mm high. Follow Panasonic's measured reflow profile or its
   iron-soldering limits; support the populated underside.
4. Inspect pin bridges and polarity under magnification. Assemble the top-side
   BOOT/RESET and eight channel-reset switches without remelting unsupported bottom-side parts.
5. Fit through-hole connectors, fuse clips and input terminals last. Large copper
   pours and REDCUBE terminals require board preheat and a sufficiently powerful,
   temperature-controlled process. Wuerth 74650195 is a THR terminal: use its
   specified solder process and verify full barrel wetting on all nine pins.
   A hand-solder process on this heavy-copper board must be demonstrated on the
   first assembly; a surface fillet does not establish hole fill. Do not increase
   temperature/dwell indefinitely.
6. Use a current-limited bench supply for initial logic bring-up, with no branch
   fuses/loads installed. Verify 3V3, reset, programming and all OFF states first.
   Do not perform initial short-circuit or reverse-battery tests on a house bank.

## Counts and mechanical checks

Each F1-F8 symbol represents **three** Keystone 3557 clips: 24 clips per board,
**72 clips for three boards**, plus 24 branch fuse inserts. Install only one fuse
per three-clip cell. Move the fuse between AUTO and BYPASS only with power removed.

Each board uses eight Wuerth 691218410002 output blocks: **24 blocks total**.
Pin 1 is ground; pin 2 is the positive load output. The body is 21.5 mm tall and
overhangs the PCB's output edge by approximately 2.7 mm. Check the enclosure and
tool/wire-entry access with actual parts. The manufacturer's EU and UL terminal
torque entries differ; do not blindly convert one into the other. Consult the
[output drawing](https://www.we-online.com/components/products/datasheet/691218410002.pdf).

J2/J3 use Wuerth 74650195 M5 blind-thread terminals: **six total**. All nine pins
must be soldered. Their 85 A component rating at 20 °C is conditional on the PCB,
lug and cable; it does not rate this board. The thread is 4 mm deep and tightening
torque is 2.2 N·m. Choose screw length for the actual lug/washer stack without
bottoming the screw; screws/lugs are not included in the component BOM. Provide
cable strain relief so these soldered terminals do not carry cable bending loads.
See the [input drawing](https://www.we-online.com/components/products/datasheet/74650195.pdf).

On 2026-09-19 the owner confirmed that real clips and an ATO fuse fit both
positions of the printed three-clip footprint, and both Wuerth connector types
fit their printed footprints. This pre-order fit check is complete; repeat it
if the footprints change. The clip footprint uses **1.7 mm finished
holes**, not the old README's 1.6 mm claim. Generated 3D bodies are inspection
envelopes, not dimensionally complete manufacturer models.

## Revision C details

The PCB is **334 × 172 mm**, four layers using JLCPCB JLC041622-3313 with 2 oz
outer and inner copper. Do not use the obsolete OSH Park files. CAM review packages
include `assembly-F-1to1.pdf` and `assembly-B-1to1.pdf`; print at actual size,
without fit-to-page. Each assembly drawing is viewed from its component side:
the bottom PDF is mirrored for readable bottom-side placement. Part values are
omitted from these drawings to keep reference designators readable; use the BOM
for values and exact MPNs. Gerbers retain the manufacturer's standard orientation.

U9 is the fixed-3.3 V TPSM63603V3 module, not the superseded discrete buck.
Follow its pin-1 orientation and separated VIN, PGND and output lands. U1–U8
exposed pads are VS. Q3/Q4 LFPAK88 drains are their mounting bases. R20's small
Kelvin terminals are sense connections, not alternate power terminals. Inspect
their isolation and continuity. Never substitute TPS2493 for latch-off U14 or U21–U28.

C7/C8/C12/C13 are now GCM32ER70J476KE19L (47 µF, 6.3 V X7R), not the
old 22 µF/10 V parts. These are 3.3 V output capacitors; never fit them on the
input rails. Their exact-model capacitance screen passes with engineering reserve.

Do the staged checks in [bring-up.md](bring-up.md). Prototype fabrication is
released under [these limits](prototype-release.md). Physical startup/fault,
USB current budget, regulator stability and 40 A thermal results remain open.

## Installation is not yet specified

The owner has deferred installation details; see [confirmed scope](design-constraints.md).
Initial USB programming is with house-bank power disconnected, then updates are
OTA. External relays remain an optional owner-provided pump interface, not added
to this PCB/BOM. Suppress their coils and keep pump motor current on the separately
protected relay-contact circuit when using that arrangement.

No onboard main fuse or MIDI holder is planned. The upstream fuse, holder, feeder,
ring lugs, M5 fastening stack, enclosure screws and strain relief must be specified
for the actual bank and installation. A 50 A upstream fuse is only a candidate,
not approved merely because the total-load target is 40 A. Battery fault interrupt
rating, conductor protection, temperature and clearing time still need review.
Do not use this unqualified board for bilge pumps or other life/safety-critical loads.

Fit all twelve M3 standoffs. Hardware must fit inside the 4 mm clearance radius.
The component BOM includes twelve standoffs; enclosure-specific screws are separate.
Thermal vias under exposed pads can wick paste: use controlled paste volume and
inspect the underside joint on the first assembly. See [BOM cost](bom-cost.md).

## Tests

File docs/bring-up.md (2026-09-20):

# Revision C validation and production acceptance

Status: **not performed**. These tests require assembled hardware, instruments
and a defined test fixture. Passing the saved-board CAD checks does not satisfy
them. Start with one assembled board; use the other two after the first passes.
The test record must identify PCB/schematic hashes, fitted MPNs, firmware version,
fixture protection, wiring, load models, ambient and measured waveforms.

## Required channel-isolation acceptance for revision C

With the revision-C circuit and a protected fault-test fixture,
exercise each output in AUTO and BYPASS, with mixed healthy-channel settings.
Include a short already present at power-up, a short applied during operation,
and persistent resistive overloads. Repeat across the specified supply/load and
temperature corners, including the maximum admissible healthy aggregate load.

Capture branch current, shared-bus voltage, main/branch gate and fault signals,
and 3V3/reset together. Pass requires the faulty branch to isolate without a
shared protection latch, ESP32 reset, healthy-output shutdown or interruption of
representative healthy loads. Record bus dip magnitude/duration against those
loads' operating limits; no main latch alone is insufficient evidence.

Verify hardware protection with firmware stopped and during MCU reset. Verify
that the faulty branch remains latched and can be reset locally without cycling
healthy outputs; a persistent short must trip it again. Otherwise admissible
healthy loads must start when a different branch is shorted at power-up.
Use the staged laboratory restrictions below; these are required tests, not
a substitute for a protected fault-test fixture.

## Prototype release and initial limits

[Prototype release](prototype-release.md) records the completed design screen,
physical-fit confirmation and CAD/CAM basis for ordering. The startup validation
target is 9.5–16 V, with 1000 µF maximum actual load capacitance per channel plus
a full-voltage resistive load of 10 A on CH1/2/8 or 5 A on CH3–7. CH8's lower
startup allowance does not change its 20 A fuse ceiling. The combined steady-load
target remains 40 A. Electronic and constant-power loads require their own checks.
The shared bus has 2880 µF nominal reservoir capacitance; MAIN_PG_N delays branch
enable until that reservoir charges. Verify the PG interlock and all local resets.
Initial TIMER must be at or below 1.04 V for the residual-time startup screen.

Follow the [clamp review's staged laboratory procedure](input-clamp-review.md).
Initially use a protected bench source, no external inductive loads and no live
short. Begin without branch fuses, at or below 1 A current limit, then at most
5 A as needed after rail checks. Account for the supply's output-capacitor
energy; current limiting alone does not bound a fault pulse.

Measure raw input below 45 V, protected bus below 27 V and local TPS2492 OUT
above −0.8 V. These are acceptance goals, not protection circuits. Keep Q3/Q4
mounting bases at or below 60 °C for the saved SOA screen; package-top or ambient
temperature alone does not prove this. Advance to larger startup, steady-load and
fault tests only after recording the preceding waveforms and bounding fixture
energy. Review a high-current energized-short fixture before using it.

## Assembly inspection and logic

1. Check the 334 x 172 mm outline, finished holes and all connector/fuse footprints
   against real parts and the 1:1 drawings. Confirm one fuse per three-clip cell;
   J1/J6–J12 pin 1 is GND and pin 2 is LOAD+. Check all nine pins of each input
   terminal and support the ESP32 overhang.
2. Inspect solder joints and polarity before power. U1–U8 thermal pads are VS, including their thermal vias;
   U21–U28 local controller grounds and clamps must be correct. U9 PGND/output pads follow its separate land pattern. Q3/Q4 and Q11–Q18 mounting bases
   are drains. Do not infer continuity from a 3D picture.
3. Use a current-limited bench supply and external fixture protection. Start
   without branch fuses or external loads. Measure VIN and 3V3; confirm reset,
   BOOT and UART access. Check every input and output remains OFF during reset,
   firmware boot, watchdog reset and brownout.
4. Disconnect the battery connector completely for USB tests. At the board's
   USB connector, test VBUS at 4.0, 4.4, 4.75 and 5.25 V. The 4.0 V case is a
   margin exploration, not a promised minimum host voltage. Measure startup,
   flash/program/reset cycles, USB enumeration, ripple and peak/average input
   current. Repeat with a representative long cable and powered hub. Verify
   host current-budget compliance before enumeration and after configuration;
   successful enumeration alone does not prove compliance.
5. Check the 3V3 rail remains inside the ESP32/module limits through boot and RF
   load steps, with no oscillation, dropout or unwanted branch activation. Log
   output-capacitance conditions and temperature. Check RF performance with the
   final mechanical surroundings; no copper under the antenna is only a layout
   prerequisite.

## Input protection and loaded startup

Probe source voltage, shunt differential voltage, bus voltage, TIMER and each
pass FET's VGS/VDS. Record current and temperature per device; do not assume equal
linear-mode sharing. Validate probe common-mode range and bandwidth first.

| Test | Conditions | Acceptance |
|---|---|---|
| Static thresholds | Sweep UV/OV slowly in both directions | Thresholds and hysteresis inside the completed tolerance analysis; no chatter |
| Mixed AUTO/BYPASS startup | 9.5, 12 and 16 V; cold and hot; resistor and representative electronic loads; sweep capacitance | Starts within the declared envelope; outside it, either starts within component limits or safely latches on a sustained limiting fault |
| Timer/fault behavior | Startup overload, overload after steady operation, repeated short load pulses | Fault timing matches the corner analysis; no unintended timed retry; cumulative timer behavior understood |
| Fast short | Protected laboratory short fixture, including hot steady operation | Peak current, VDS, VGS, bus undershoot and clamp stress remain within the reviewed limits |
| Reset/recovery | Input interruption, shallow/deep brownout and OV recovery with loads attached | Explicitly characterize UVEN/UVLO latch reset; no claim of nonvolatile latch-off |
| Reverse polarity | Current-limited source, progressing only within the approved test envelope | Blocking works in AUTO and BYPASS; leakage and component stress within their limits |
| Transients | Defined source/load inductance and stored energy | Peak voltage, pulse power and accumulated energy meet the approved clamp/SOA analysis |

Do not increase R17 power limit or C18 timeout merely to obtain a successful
startup: both changes require repeating the single-FET SOA and fault analysis.
Do not move fuses with battery power connected.

## Load, thermal and branch protection

Test the complete positive **and return** paths. Record four-wire voltage drops
across input terminals, Q1/Q2, R20, Q3/Q4, common bus, each active fuse/holder,
PROFET, output terminal and return path. Instrument source/drain via banks,
shunt terminals, the ground terminal and CH8 spreading copper.

Increase total load in controlled steps to 40 A with distributions that maximize
input-stage heating and far-end bus/CH8 heating. Include AUTO, BYPASS and mixed
positions. Use branch currents within the fuse manufacturer's ambient derating;
a fuse's printed 20 A maximum is not permission to run it at 20 A continuously.
Repeat at the declared operating ambient/cooling conditions and until thermal
steady state, then repeat hot startup and fault tests. Record current sharing
between each MOSFET pair. Stop at the reviewed case/junction/terminal limits;
those limits must be set before testing, not inferred from a component surviving.

Verify branch-fuse/PROFET coordination with the actual approved fuse series and
representative inrush/stall loads. No arbitrary motor, relay or upstream fuse is
qualified by this board-level test plan. A final installation rating also needs
the installation inputs that the owner deliberately deferred.

## Acceptance records

A prototype-fabrication release requires engineering closure and the exact source
hashes from `just verify`. A **production** release additionally requires the
recorded bench, fault, USB and thermal results above, a defined operating/load
rating, assembly inspection criteria and a functional check for each built board.
`docs/release-status.json` must distinguish these two decisions. No test results
or production rating exist yet.

## Revision C monitoring and probe map

Use TP1 ground; TP2/3 raw/intermediate battery; TP4/5 Kelvin VCC/SENSE;
TP6 common TIMER; TP7 common gate; TP8 shared bus; TP9 VIN; TP10 3V3;
TP11 IMON; TP12 common FLT; TP13 common PG; TP14 branch enable;
TP15 ADC_IMON; TP16 ADC_BUS. TP17–24 are branch TIMER1–8.

Update firmware IN1 to IO15 before AUTO tests. ADC IO5 is IMON, IO7 is bus;
nominal scaling is 24 mV/A and 0.08 V/V. Calibrate against an external meter.
Common fault is IO42; local faults use IO16/17/18/35/36/37/39/40.
Check fault reporting with no load and during MCU reset. Hardware isolation must
still work when reporting firmware is absent.

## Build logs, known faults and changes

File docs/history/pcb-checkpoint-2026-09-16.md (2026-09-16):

# PCB work checkpoint — paused 2026-09-16

The owner requested documentation, a commit and GitHub push, then a pause.
**NOT READY TO ORDER. No fabrication release, PCB order or parts purchase.**
Resume the existing work; do not repeat the owner decisions.

## Decisions already made

- 40 A simultaneous continuous **design target**, not a measured/qualified rating.
- Approved operating-input range **9.5–16 V**; reverse blocking and OV disconnect
  around 17 V. Higher-voltage charging/equalization may disconnect the outputs.
- Mixed AUTO/BYPASS positions at startup are required. Do not assume unloaded
  startup or ask the owner to move fuses live.
- Excessive startup current/input overcurrent must latch off until battery power
  is cycled; no timed automatic retry or firmware-dependent protection.
- Upstream main fuse, no onboard MIDI/main fuse. F9 protects the logic branch.
- Enlargement and heavier copper are approved. Selected service/stackup:
  JLCPCB JLC041622-3313, four layers, 2 oz outer and inner, nominal 1.6 mm, ENIG.
- Three boards to assemble by hand, with paste/hot air/hot plate available. Exact
  BOM parts must be in DigiKey stock in the required quantities.
- Direct-entry screw outputs. Channel maximum fuses 10/10/5/5/5/5/5/20 A;
  F9 maximum 2 A. Circuit number and maximum fuse size on silk.
- USB only for initial bench programming **with the battery disconnected**;
  subsequent firmware updates OTA.
- Battery/charger, installation, enclosure/cooling and exact loads remain
  deliberately unspecified. Do not turn these unknowns into verified ratings.
- Host PC freezes remain unresolved. PC hardware testing is deferred.
  Preserve crash-resistant saves. PCB prototype validation is still required.

## Exact file state

| Artifact | Checkpoint state |
|---|---|
| `tools/design.py`, generated schematic and custom symbol library | New TPS2492 input stage implemented; last ERC report had zero messages |
| `eswitch.kicad_pcb` | **221 × 75 mm**, older input stage; retained routed revision-B work, NOT matching the new schematic |
| `tools/input_stage.py`, `gen_pcb.py`, `layout_revision_b.py` | New stage source targeting **253 × 75 mm**; latest routing edits not successfully generated/verified |
| `tools/migrate_input_stage.py` | In-progress migration preserving channel/MCU routing; currently has an intermittent KiCad/SWIG failure |
| `fab/digikey/` | 55-line exact-MPN BOM and stock audit for three builds, observed 2026-09-16; not a reservation or release |
| `docs/release-status.json` | Explicitly blocked; stale historical zero-DRC/parity values replaced with unknowns |
| Old Gerber ZIPs / OSH Park upload | Obsolete; do not order |

Tracked PCB checkpoint SHA-256:

`6482993dbfc8724b58c9914ae6316859a5164590e9f5e608c9476d0aa4b7ba22`

At pause, `out/revb-before-latch.kicad_pcb` has the **same hash** as the tracked
PCB. Migration reads that fixed snapshot and writes only
`out/latch-candidate.kicad_pcb`. Recreate the snapshot from this commit's tracked
PCB on a fresh checkout; it is not an additional uncommitted design. Its matching
project snapshot is also under `out/`.

`out/` is ignored scratch data, not release source. The latest successfully saved
candidate and its `out/latch-drc.json` precede the newest source edits. That DRC
reported **19 unconnected items** and numerous copper errors (41 shorting-item,
24 clearance and 16 crossing reports, plus other types). These counts describe
the stale candidate only, not the tracked board or latest generator.
**Do not promote it.**

## Implemented work preserved

- TPSM63603 fixed-3.3 V buck-module circuit, custom TI footprint, compact local
  power layout and AGND net tie. Effective output capacitance still needs proof.
- USB-only LM74800 ideal-diode feed, USB ESD and deliberate differential routing;
  selected heavy-copper stackup and USB reference-plane keepouts.
- Local PROFET decoupling/input networks, wider copper and revised placement.
- Reverse-input and hardware latch-off circuit, shunt footprint and new stock
  evidence. See `docs/input-protection-review.md` for selected parts and values.
- Atomic PCB writes in `tools/pcb_io.py`, native net/metadata handling, project
  fabrication-rule persistence, and guarded low-speed signal-gap repair.
- Updated schematic, libraries, BOM and dated DigiKey/manufacturer evidence.

## First issue on resume: migration

Two identified bugs were fixed and verified in an earlier successful candidate:

1. KiCad `GetStart()`/`GetEnd()` expose live C++ vectors. Modifying a segment
   before copying both endpoints made a 32 mm inserted bridge become 64 mm.
   Endpoints are now copied by numeric value before mutation.
2. Moved zone outlines retained obsolete filled polygons. Connectivity through
   stale fills changed some retained vias to GND. All fills are now cleared before
   rebuilding connectivity; retained-net assertions surround connectivity/fill.

However, the **latest** attempt failed before saving at `board.GetNetsByName()`:

```
AttributeError: 'SwigPyObject' object has no attribute 'NetsByName'
```

It also printed many SWIG wrapper leak warnings. An earlier similar failure
occurred accessing footprint references. Retaining detached track wrappers helped
previously but did not make mutation reliable. The saved source now includes
`translated_source()`, an S-expression geometry/removal transform followed by a
KiCad reload, with the former SWIG mutation loops disabled. This workaround has
**not** had a successful verification run in the checkpoint. Do not claim the
failure is resolved. Review/test the transform and then remove obsolete disabled
code. KiCad 10 board net entries use names, not old numeric-net assumptions;
preserve footprint-local coordinates and board-level zone geometry.

Latest unverified edits rotate U14 and D7 to 270 degrees, move passives/F9 and
rewrite stage routes. Migration leaves selected bridges through the new stage
open where Y < 50 mm for guarded rerouting; existing signal ends are retained.
Check actual pad positions before trusting hard-coded fanout.
`out/latch-pads.json` is stale until a successful new run. Historical `obsolete_*`
functions remain; remove them only after the active implementation is proven.

## Remaining work, in order

1. Make migration repeatable; verify retained nets, footprint identities and
   inserted geometry. Resolve stage shorts, clearance, courtyard and mask
   conflicts. Do not overwrite the tracked board with a worse candidate.
2. Complete TPS2492 worst-case current/power limit, UV/OV threshold, timer, loaded
   startup and **single-FET hot SOA** analysis. Do not assume parallel MOSFETs
   share linear-mode startup. Verify clamps, inductance and fast-short gate
   behavior. Deep UVLO/UVEN brownout resets the latch; it has no nonvolatile memory.
3. Finish low-speed signal gaps and GND islands. Before migration, the tracked
   board's latest local report had nine gaps: six GND islands, ISP3, INR2 and IN3.
   Those are not the new candidate's gap count.
4. Check **both** 40 A positive and return paths, source/drain/shunt necks,
   copper/via current transfer, and CH8 thermal paths. Fuse limits are not
   continuous-current ratings. Define prototype thermal/startup/fault tests.
5. Verify buck effective capacitance with manufacturer DC-bias data. Four
   GRM32ER71A226KE20L 22 µF capacitors are fitted; nominal 88 µF does not prove
   effective minimum. Verify USB bench startup/current budget and continuous In2
   GND reference under the B.Cu USB pair.
6. Fresh ERC, native DRC, schematic parity, independent pin-net comparison,
   antenna/reference-plane review, fuse silk and mechanical drawing review.
   Physical fit/thermal tests are prototype bring-up, not completed results.
7. Update `justfile`, legacy finish/stitch and packaging. `tools/fab_package.py`
   still targets the old OSH Park board. **Do not run `just all` or legacy
   finish/stitch blindly**; they can replace carefully migrated routing.
   Strengthen release checks with fresh artifact evidence.
8. Update assembly docs (new buck, heavy copper, thermal pads, Wuerth THR input
   terminal process), refresh stock if stale, generate and visually inspect
   Gerbers/drills/outline/silk and an unambiguous JLC order specification.
9. Only after closure: approve prototype fabrication, commit/push and hand off
   checked upload. Do not claim tested marine suitability.

## Local tools and evidence

- KiCad 10.0.6 through mise/AppImage: `mise exec -- kicad python3.11 tools/...`.
  Limit CPU-heavy work if useful (`taskset -c 0,1`); do not troubleshoot the PC now.
- KiCad Python NumPy: `out/py311`; host PDF/scientific helpers:
  `out/review-python`. Ignored dependencies can be recreated as needed.
- `tools/route_gaps.py` is for permitted low-speed signals, **not** power paths,
  USB impedance routing or blindly connecting GND islands.
- `docs/fabrication-stackup-evidence.json` records manufacturer calculator output.
  B.Cu USB nominal width/gap 0.235/0.215 mm for selected 90 Ω stackup;
  do not substitute stackup without recalculating.
- Downloaded PDFs under `out/datasheets/`: `tps2492.pdf`, `psmn1r8-80sse.pdf`,
  `css4j-4026.pdf`, and prior evidence. Manufacturer URLs are in reviews/BOM.
  `out/nexperia-soa.png` and `out/shunt-land.png` are useful drawing references.
- Interpret Nexperia red/black SOA curves correctly before deriving a hot-case
  limit; do not substitute the headline package power rating.
- Last saved ERC report: 2026-09-16 08:48:46, zero errors/warnings. It does not
  validate the mismatched PCB or new layout.

Four randomized `.eswitch-*.kicad_pro` sidecars from earlier atomic saves were
removed during checkpoint cleanup. The real project remains; no source design
or routed PCB was removed.

Checkpoint checks: `git diff --check`, Python source compilation and independent
netlist validation passed. Regenerated BOM audit passed for 55 lines/three builds.
The release checker rejected fabrication as intended. No new full DRC/parity or
physical tests were run for this pause-and-save request.

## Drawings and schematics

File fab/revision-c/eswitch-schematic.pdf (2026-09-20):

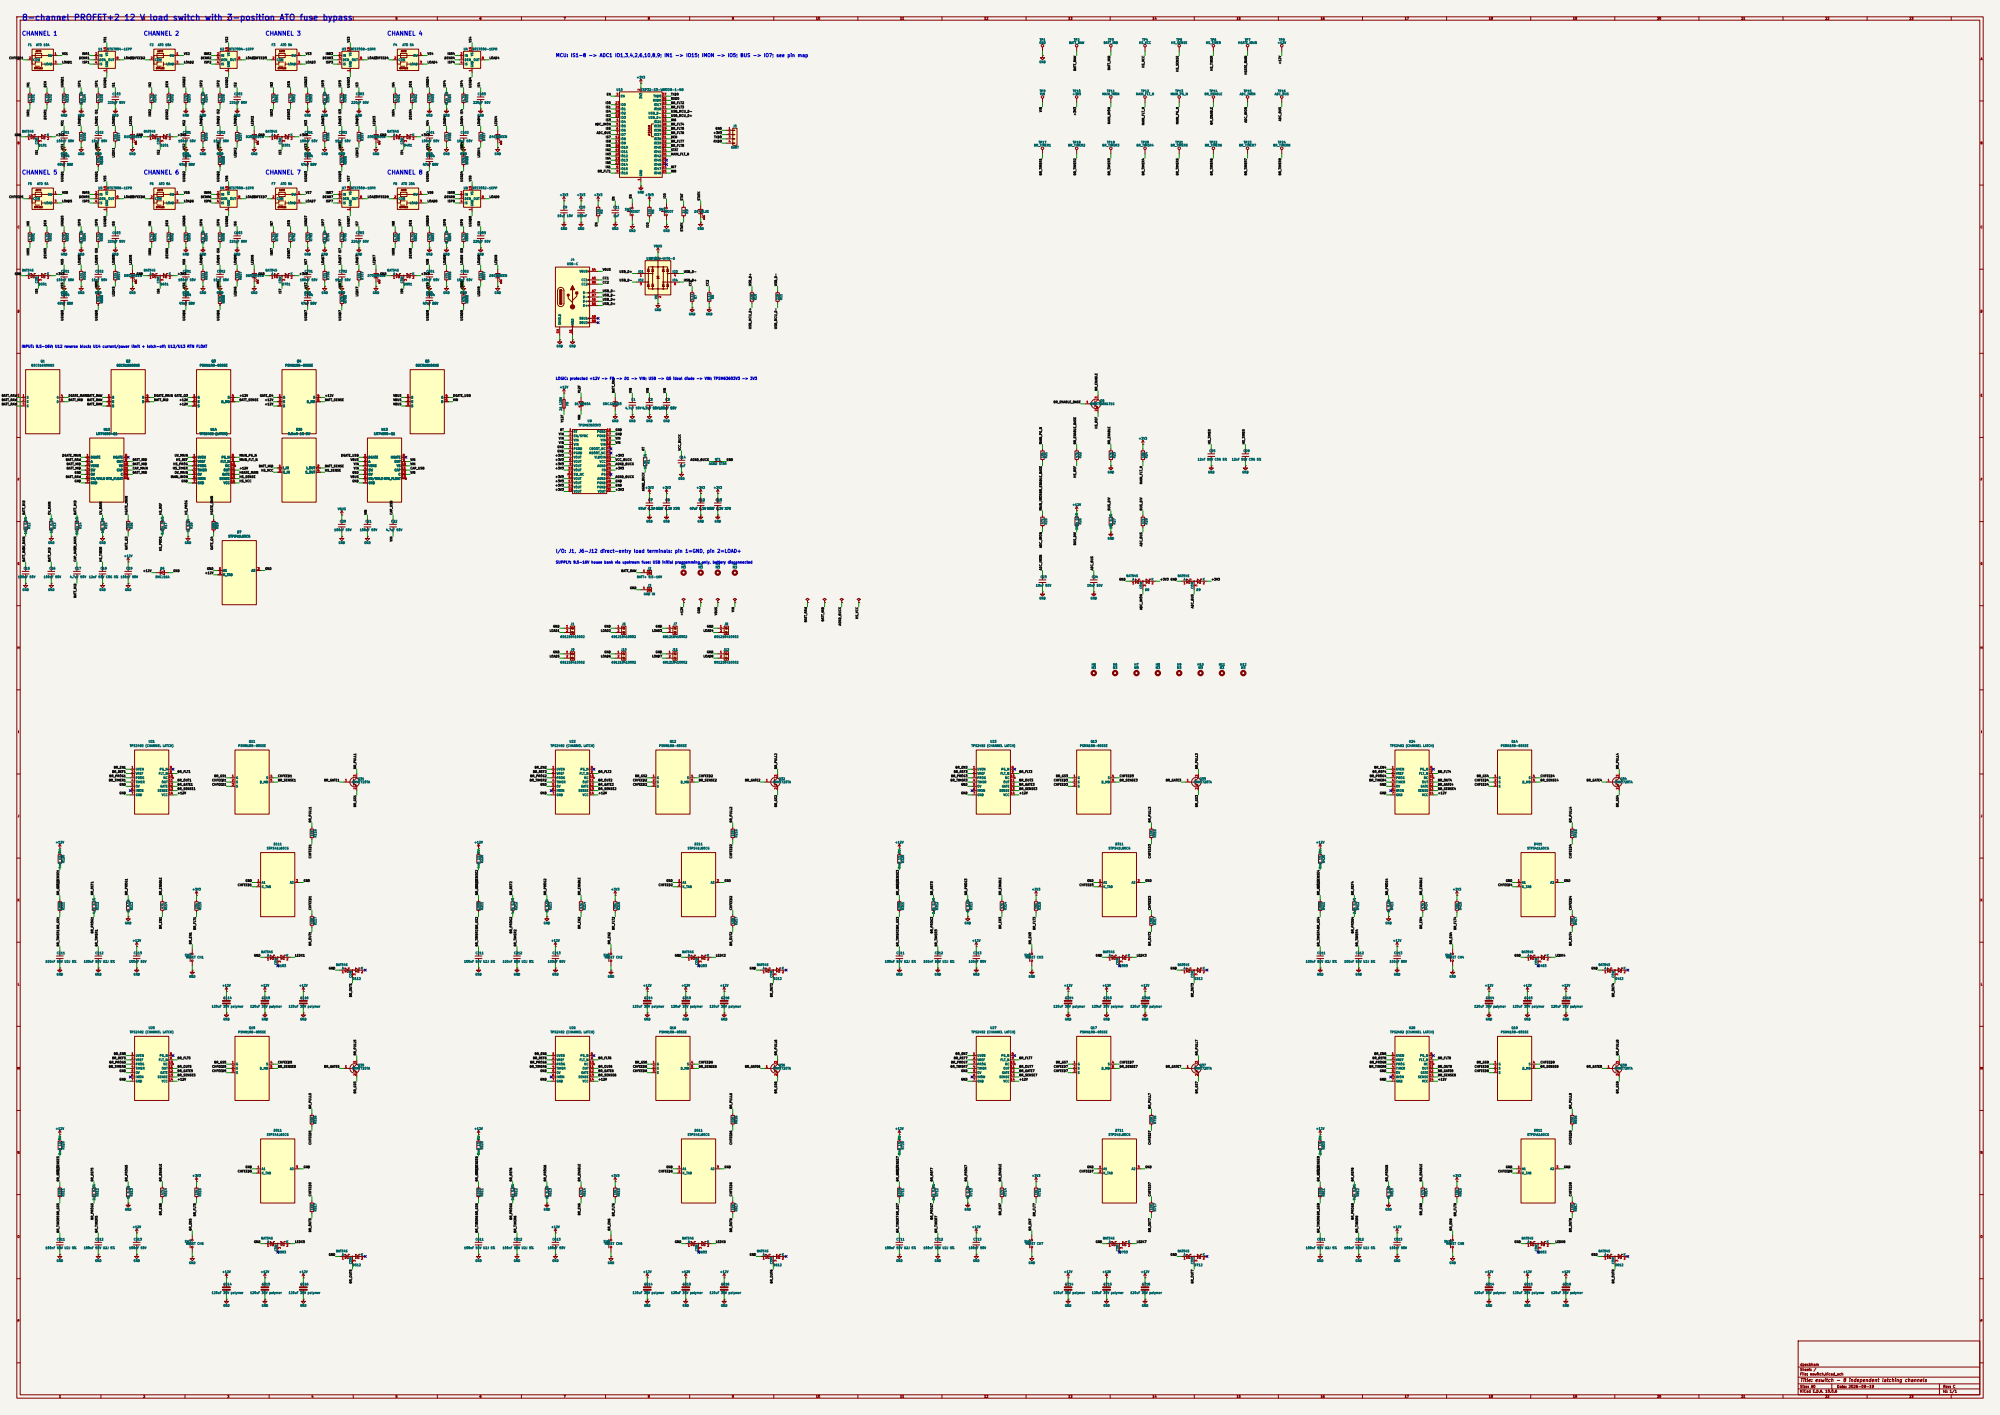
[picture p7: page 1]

8-channel PROFET+2 12 V load switch with 3-position ATO fuse bypass

MCU: IS1-8 -> ADC1 IO1,3,4,2,6,10,8,9; IN1 -> IO15; IMON -> IO5; BUS -> IO7; see pin map

INPUT: 9.5-16V; U12 reverse block; U14 current/power limit + latch-off; U12/U13 RTN FLOAT

LOGIC: protected +12V -> F9 -> D1 -> VIN; USB -> Q5 ideal diode -> VIN; TPSM63603V3 -> 3V3

I/O: J1, J6-J12 direct-entry load terminals: pin 1=GND, pin 2=LOAD+

SUPPLY: 9.5-16V house bank via upstream fuse; USB initial programming only, battery disconnected

Sheet: /
File: eswitch.kicad_sch
Title: eswitch - 8 independent latching channels

Size: A0 | Rev: C
KiCad E.D.A. 10.0.6 | Id: 1/1

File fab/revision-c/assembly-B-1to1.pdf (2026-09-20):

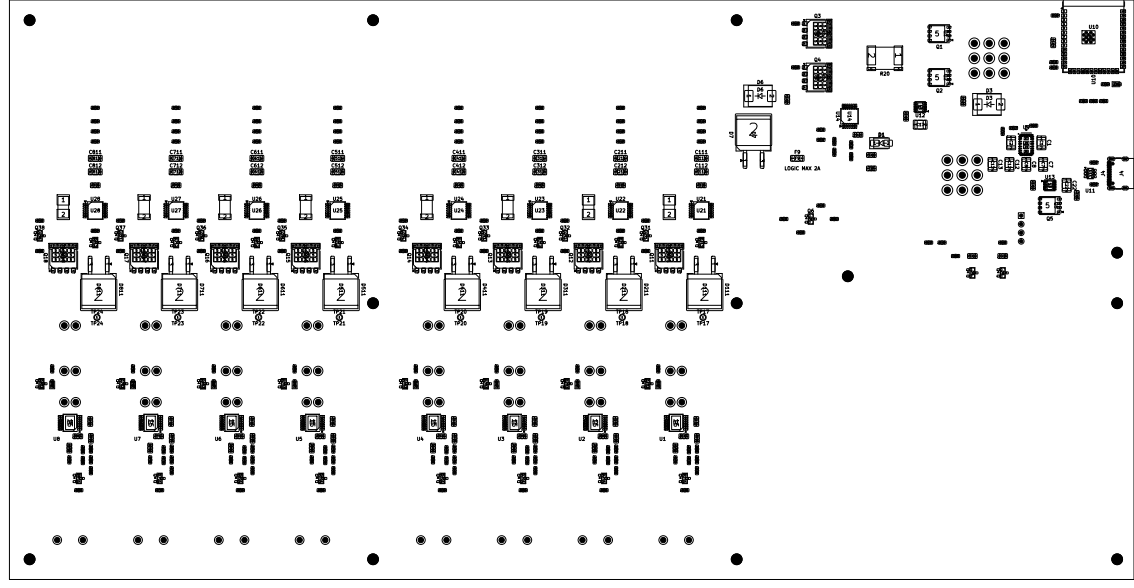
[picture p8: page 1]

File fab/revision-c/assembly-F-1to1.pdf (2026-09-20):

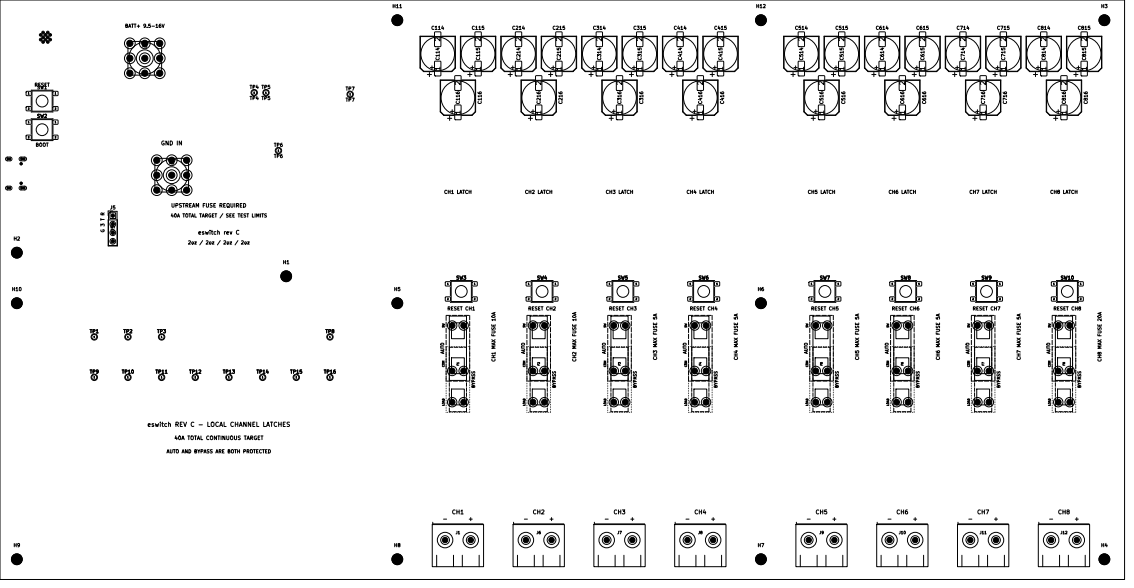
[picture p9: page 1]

2oz / 2oz / 2oz / 2oz AUTO AND BYPASS ARE BOTH PROTECTED

eswitch REV C - LOCAL CHANNEL LATCHES

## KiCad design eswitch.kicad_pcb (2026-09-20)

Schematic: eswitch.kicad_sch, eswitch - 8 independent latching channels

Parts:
C1, C2, C17, C22: 4.7uF 50V; C_1210_3225Metric; MPN GRM32ER71H475KA88L
C3: 100nF 50V; C_0603_1608Metric; MPN CC0603JRX7R9BB104
C7, C8, C12, C13: 47uF 6.3V X7R; C_1210_3225Metric; MPN GCM32ER70J476KE19L
C9: 10uF 10V; C_0805_2012Metric; MPN CC0805KKX5R6BB106
C10: 100nF; C_0603_1608Metric; MPN CC0603JRX7R9BB104
C11, C14: 1uF; C_0603_1608Metric; MPN CC0603KRX7R7BB105
C15, C16, C19, C20, C21, C101, C113, C201, C213, C301, C313, C401, C413, C501, C513, C601, C613, C701, C713, C801, C813: 100nF 50V; C_0805_2012Metric; MPN CL21B104KBCNNNC
C18, C25, C28: 12nF 50V C0G 5%; C_0805_2012Metric; MPN C0805C123J5GACTU
C23, C24, C102, C202, C302, C402, C502, C602, C702, C802: 10nF 50V; C_0805_2012Metric; MPN CL21B103KBANNNC
C103, C203, C303, C403, C503, C603, C703, C803: 220pF 50V; C_0603_1608Metric; MPN CL10C221JB8NFNC
C104, C204, C304, C404, C504, C604, C704, C804: 47nF 50V; C_0805_2012Metric; MPN CL21B473KBCNNNC
C111, C112, C211, C212, C311, C312, C411, C412, C511, C512, C611, C612, C711, C712, C811, C812: 100nF 50V U2J 5%; C_1206_3216Metric; MPN C1206C104J5JACAUTO
C114, C115, C116, C214, C215, C216, C314, C315, C316, C414, C415, C416, C514, C515, C516, C614, C615, C616, C714, C715, C716, C814, C815, C816: 120uF 35V polymer; CP_Elec_10x12.6; MPN 35SVPF120M
D1: B360A; D_SMA; MPN B360A-13-F
D3: SMCJ24CA; D_SMC; MPN SMCJ24CA
D5: BLUE; LED_0603_1608Metric; MPN 150060BS75000
D6: SMCJ16A; D_SMC; MPN SMCJ16A
D7, D111, D211, D311, D411, D511, D611, D711, D811: STPS41L60CG; TO-263-2; MPN STPS41L60CG-TR
D8, D9, D101, D103, D112, D201, D203, D212, D301, D303, D312, D401, D403, D412, D501, D503, D512, D601, D603, D612, D701, D703, D712, D801, D803, D812: BAT54S; SOT-23; MPN BAT54S-QR
D102, D202, D302, D402, D502, D602, D702, D802: GREEN; LED_0603_1608Metric; MPN 150060GS75000
F1, F2: ATO 10A; Fuseholder_ATO_3pos_Keystone_3557; MPN 3557
F3, F4, F5, F6, F7: ATO 5A; Fuseholder_ATO_3pos_Keystone_3557; MPN 3557
F8: ATO 20A; Fuseholder_ATO_3pos_Keystone_3557; MPN 3557
F9: 2A 1206; Fuse_1206_3216Metric; MPN 0466002.NR
H1, H2, H3, H4, H5, H6, H7, H8, H9, H10, H11, H12: M3; MountingHole_3.2mm_M3
J1, J6, J7, J8, J9, J10, J11, J12: 691218410002; TerminalBlock_1x02_P7.62mm_Wuerth_2184; MPN 691218410002
J2: BATT+ 9.5-16V; ScrewTerminal_Wuerth_74650195_M5; MPN 74650195
J3: GND IN; ScrewTerminal_Wuerth_74650195_M5; MPN 74650195
J4: USB-C; USB4105_NPTH_0p2; MPN USB4105-GF-A
J5: UART; PinHeader_1x04_P2.54mm_Vertical; MPN 61300411121
NT1: AGND STAR; NetTie-2_SMD_Pad0.5mm
Q1, Q2, Q5: BSC016N06NS; Infineon_PG-TDSON-8_6.15x5.15mm; MPN BSC016N06NSATMA1
Q3, Q4, Q11, Q12, Q13, Q14, Q15, Q16, Q17, Q18: PSMN1R8-80SSE; LFPAK88; MPN PSMN1R8-80SSEJ
Q6: MMBT3906LT1G; SOT-23; MPN MMBT3906LT1G
Q31, Q32, Q33, Q34, Q35, Q36, Q37, Q38: FMMT720TA; SOT-23; MPN FMMT720TA
R1: 16.5k 1%; R_0603_1608Metric; MPN RC0603FR-0716K5L
R5, R6, R21, R24, R107, R115, R207, R215, R307, R315, R407, R415, R507, R515, R607, R615, R707, R715, R807, R815: 10k; R_0603_1608Metric; MPN RC0603FR-0710KL
R7, R8: 5.1k; R_0603_1608Metric; MPN ERJ-3EKF5101V
R9: 1k; R_0603_1608Metric; MPN RC0603FR-071KL
R10, R11: 22R; R_0603_1608Metric; MPN ERJ-3EKF22R0V
R12, R26: 115k 0.1%; R_0603_1608Metric; MPN RT0603BRD07115KL
R13, R15, R27: 10k 0.1%; R_0603_1608Metric; MPN RT0603BRD0710KL
R14: 56.2k 0.1%; R_0603_1608Metric; MPN RT0603BRD0756K2L
R16, R19, R116, R117, R216, R217, R316, R317, R416, R417, R516, R517, R616, R617, R716, R717, R816, R817: 10R; R_0603_1608Metric; MPN RC0603FR-0710RL
R17: 8.25k 0.1%; R_0603_1608Metric; MPN RT0603BRD078K25L
R18, R113, R213, R313, R413, R513, R613, R713, R813: 1k 0.1%; R_0603_1608Metric; MPN RT0603BRD071KL
R20: 0.5mR 1% 5W; Bourns_CSS4J_4026; MPN CSS4J-4026R-L500F
R22, R23, R25, R28, R106, R108, R114, R206, R208, R214, R306, R308, R314, R406, R408, R414, R506, R508, R514, R606, R608, R614, R706, R708, R714, R806, R808, R814: 47k; R_0603_1608Metric; MPN RC0603FR-0747KL
R101, R102, R105, R201, R202, R205, R301, R302, R305, R401, R402, R405, R501, R502, R505, R601, R602, R605, R701, R702, R705, R801, R802, R805: 4.7k; R_0603_1608Metric; MPN RC0603FR-074K7L
R103, R203, R303, R403, R503, R603, R703, R803: 47R; R_0805_2012Metric; MPN RC0805FR-0747RL
R104, R204: 2.2k 1%; R_0603_1608Metric; MPN RC0603FR-072K2L
R111, R211, R311, R411, R511, R611, R711, R811: 100R; R_0603_1608Metric; MPN RC0603FR-07100RL
R112, R212: 4.7k 0.1%; R_0603_1608Metric; MPN RT0603BRD074K7L
R120, R220: 4mR 1% 3W; WSLP2512_2m; MPN WSLP25124L000FEA
R304, R404, R504, R604, R704: 3.3k 1%; R_0603_1608Metric; MPN RC0603FR-073K3L
R312, R412, R512, R612, R712: 2.2k 0.1%; R_0603_1608Metric; MPN RG1608P-222-B-T5
R320, R420, R520, R620, R720: 8mR 1% 3W; WSLP2512_8m; MPN WSLP25128L000FEA
R804: 1.2k 1%; R_0603_1608Metric; MPN RC0603FR-071K2L
R812: 7.5k 0.1%; R_0603_1608Metric; MPN RT0603BRD077K5L
R820: 2mR 1% 3W; WSLP2512_2m; MPN WSLP25122L000FEA
SW1: RESET; SW_SPST_PTS645Sx43SMTR92; MPN PTS645SM43SMTR92 LFS
SW2: BOOT; SW_SPST_PTS645Sx43SMTR92; MPN PTS645SM43SMTR92 LFS
SW3: RESET CH1; SW_SPST_PTS645Sx43SMTR92; MPN PTS645SM43SMTR92 LFS
SW4: RESET CH2; SW_SPST_PTS645Sx43SMTR92; MPN PTS645SM43SMTR92 LFS
SW5: RESET CH3; SW_SPST_PTS645Sx43SMTR92; MPN PTS645SM43SMTR92 LFS
SW6: RESET CH4; SW_SPST_PTS645Sx43SMTR92; MPN PTS645SM43SMTR92 LFS
SW7: RESET CH5; SW_SPST_PTS645Sx43SMTR92; MPN PTS645SM43SMTR92 LFS
SW8: RESET CH6; SW_SPST_PTS645Sx43SMTR92; MPN PTS645SM43SMTR92 LFS
SW9: RESET CH7; SW_SPST_PTS645Sx43SMTR92; MPN PTS645SM43SMTR92 LFS
SW10: RESET CH8; SW_SPST_PTS645Sx43SMTR92; MPN PTS645SM43SMTR92 LFS
TP1: GND; TestPoint_Pad_D1.5mm
TP2: BATT_RAW; TestPoint_Pad_D1.5mm
TP3: BATT_MID; TestPoint_Pad_D1.5mm
TP4: HS_VCC; TestPoint_Pad_D1.5mm
TP5: HS_SENSE; TestPoint_Pad_D1.5mm
TP6: HS_TIMER; TestPoint_Pad_D1.5mm
TP7: HGATE_MAIN; TestPoint_Pad_D1.5mm
TP8: +12V; TestPoint_Pad_D1.5mm
TP9: VIN; TestPoint_Pad_D1.5mm
TP10: +3V3; TestPoint_Pad_D1.5mm
TP11: MAIN_IMON; TestPoint_Pad_D1.5mm
TP12: MAIN_FLT_N; TestPoint_Pad_D1.5mm
TP13: MAIN_PG_N; TestPoint_Pad_D1.5mm
TP14: BR_ENABLE; TestPoint_Pad_D1.5mm
TP15: ADC_IMON; TestPoint_Pad_D1.5mm
TP16: ADC_BUS; TestPoint_Pad_D1.5mm
TP17: BR_TIMER1; TestPoint_Pad_D1.5mm
TP18: BR_TIMER2; TestPoint_Pad_D1.5mm
TP19: BR_TIMER3; TestPoint_Pad_D1.5mm
TP20: BR_TIMER4; TestPoint_Pad_D1.5mm
TP21: BR_TIMER5; TestPoint_Pad_D1.5mm
TP22: BR_TIMER6; TestPoint_Pad_D1.5mm
TP23: BR_TIMER7; TestPoint_Pad_D1.5mm
TP24: BR_TIMER8; TestPoint_Pad_D1.5mm
U1, U2: BTS7004-1EPP; Infineon_PG-TSDSO-14-22; MPN BTS70041EPPXUMA1
U3, U4, U5, U6, U7: BTS7008-1EPR; Infineon_PG-TSDSO-14-22; MPN BTS70081EPRXUMA1
U8: BTS7002-1EPP; Infineon_PG-TSDSO-14-22; MPN BTS70021EPPXUMA1
U9: TPSM63603V3; TI_RDH0030A_TPSM63603; MPN TPSM63603V3RDHR
U10: ESP32-S3-WROOM-1-N8; ESP32-S3-WROOM-1_Edge; MPN ESP32-S3-WROOM-1-N8
U11: SRV05-4HTG-D; SOT-23-6; MPN SRV05-4HTG-D
U12, U13: LM74800-Q1; WSON-12-1EP_3x3mm_P0.5mm_EP1.5x2.5mm; MPN LM74800QDRRRQ1
U14: TPS2492 (LATCH); TSSOP-14_4.4x5mm_P0.65mm; MPN TPS2492PWR
U21, U22, U23, U24, U25, U26, U27, U28: TPS2492 (CHANNEL LATCH); TSSOP-14_4.4x5mm_P0.65mm; MPN TPS2492PWR

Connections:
+3V3: C7.1, C8.1, C9.1, C10.1, C12.1, C13.1, D8.2 (K), D9.2 (K), D101.2 (K), D201.2 (K), D301.2 (K), D401.2 (K), D501.2 (K), D601.2 (K), D701.2 (K), D801.2 (K), J5.2, R5.1, R6.1, R24.1, R115.1, R215.1, R315.1, R415.1, R515.1, R615.1, R715.1, R815.1, TP10.1, U9.7 (VOUT), U9.8 (VOUT), U9.9 (VOUT), U9.10 (VOUT), U9.12 (VOUT), U9.13 (VOUT), U9.14 (VOUT), U9.15 (VOUT), U9.22 (VLDOIN), U9.25 (FB), U9.30 (VOUT), U10.2 (3V3)
+12V: C19.1, C113.1, C114.1, C115.1, C116.1, C213.1, C214.1, C215.1, C216.1, C313.1, C314.1, C315.1, C316.1, C413.1, C414.1, C415.1, C416.1, C513.1, C514.1, C515.1, C516.1, C613.1, C614.1, C615.1, C616.1, C713.1, C714.1, C715.1, C716.1, C813.1, C814.1, C815.1, C816.1, D6.1 (K), D7.2 (K_TAB), F9.1, Q3.2 (S), Q3.3 (S), Q3.4 (S), Q4.2 (S), Q4.3 (S), Q4.4 (S), R26.1, R120.1, R220.1, R320.1, R420.1, R520.1, R620.1, R720.1, R820.1, TP8.1, U14.11 (OUT), U21.14 (VCC), U22.14 (VCC), U23.14 (VCC), U24.14 (VCC), U25.14 (VCC), U26.14 (VCC), U27.14 (VCC), U28.14 (VCC)
/ADC_BUS: C24.1, D9.3 (COM), R28.2, TP16.1, U10.7 (IO7)
/ADC_IMON: C23.1, D8.3 (COM), R25.2, TP15.1, U10.5 (IO5)
/AGND_BUCK: NT1.1, R1.2, U9.24 (AGND), U9.27 (AGND)
/BATT_MID: C16.1, C17.2, Q1.5 (D), Q2.5 (D), R12.1, R14.1, R20.1 (I_IN), TP3.1, U12.3 (VSNS), U12.4 (SW), U12.9 (OUT), U12.10 (VS), U12.12 (C)
/BATT_RAW: C15.1, D3.1 (K), J2.1, Q1.1 (S), Q1.2 (S), Q1.3 (S), Q2.1 (S), Q2.2 (S), Q2.3 (S), TP2.1, U12.2 (A), U12.6 (EN/UVLO)
/BATT_SENSE: Q3.5 (D_MB), Q4.5 (D_MB), R20.2 (I_OUT)
/BR_EN1: R114.2, SW3.2, U21.1 (UVEN)
/BR_EN2: R214.2, SW4.2, U22.1 (UVEN)
/BR_EN3: R314.2, SW5.2, U23.1 (UVEN)
/BR_EN4: R414.2, SW6.2, U24.1 (UVEN)
/BR_EN5: R514.2, SW7.2, U25.1 (UVEN)
/BR_EN6: R614.2, SW8.2, U26.1 (UVEN)
/BR_EN7: R714.2, SW9.2, U27.1 (UVEN)
/BR_EN8: R814.2, SW10.2, U28.1 (UVEN)
/BR_ENABLE: Q6.3 (C), R23.1, R114.1, R214.1, R314.1, R414.1, R514.1, R614.1, R714.1, R814.1, TP14.1
/BR_ENABLE_BASE: Q6.1 (B), R21.2, R22.1
/BR_FLT1: R115.2, U10.9 (IO16), U21.9 (FLT_N)
/BR_FLT2: R215.2, U10.10 (IO17), U22.9 (FLT_N)
/BR_FLT3: R315.2, U10.11 (IO18), U23.9 (FLT_N)
/BR_FLT4: R415.2, U10.28 (IO35), U24.9 (FLT_N)
/BR_FLT5: R515.2, U10.29 (IO36), U25.9 (FLT_N)
/BR_FLT6: R615.2, U10.30 (IO37), U26.9 (FLT_N)
/BR_FLT7: R715.2, U10.32 (IO39), U27.9 (FLT_N)
/BR_FLT8: R815.2, U10.33 (IO40), U28.9 (FLT_N)
/BR_GATE1: Q31.1 (B), R111.1, U21.12 (GATE)
/BR_GATE2: Q32.1 (B), R211.1, U22.12 (GATE)
/BR_GATE3: Q33.1 (B), R311.1, U23.12 (GATE)
/BR_GATE4: Q34.1 (B), R411.1, U24.12 (GATE)
/BR_GATE5: Q35.1 (B), R511.1, U25.12 (GATE)
/BR_GATE6: Q36.1 (B), R611.1, U26.12 (GATE)
/BR_GATE7: Q37.1 (B), R711.1, U27.12 (GATE)
/BR_GATE8: Q38.1 (B), R811.1, U28.12 (GATE)
/BR_GS1: Q11.1 (G), Q31.2 (E), R111.2
/BR_GS2: Q12.1 (G), Q32.2 (E), R211.2
/BR_GS3: Q13.1 (G), Q33.2 (E), R311.2
/BR_GS4: Q14.1 (G), Q34.2 (E), R411.2
/BR_GS5: Q15.1 (G), Q35.2 (E), R511.2
/BR_GS6: Q16.1 (G), Q36.2 (E), R611.2
/BR_GS7: Q17.1 (G), Q37.2 (E), R711.2
/BR_GS8: Q18.1 (G), Q38.2 (E), R811.2
/BR_OUT1: D112.3 (COM), R117.2, U21.11 (OUT)
/BR_OUT2: D212.3 (COM), R217.2, U22.11 (OUT)
/BR_OUT3: D312.3 (COM), R317.2, U23.11 (OUT)
/BR_OUT4: D412.3 (COM), R417.2, U24.11 (OUT)
/BR_OUT5: D512.3 (COM), R517.2, U25.11 (OUT)
/BR_OUT6: D612.3 (COM), R617.2, U26.11 (OUT)
/BR_OUT7: D712.3 (COM), R717.2, U27.11 (OUT)
/BR_OUT8: D812.3 (COM), R817.2, U28.11 (OUT)
/BR_PROG1: R112.2, R113.1, U21.3 (PROG)
/BR_PROG2: R212.2, R213.1, U22.3 (PROG)
/BR_PROG3: R312.2, R313.1, U23.3 (PROG)
/BR_PROG4: R412.2, R413.1, U24.3 (PROG)
/BR_PROG5: R512.2, R513.1, U25.3 (PROG)
/BR_PROG6: R612.2, R613.1, U26.3 (PROG)
/BR_PROG7: R712.2, R713.1, U27.3 (PROG)
/BR_PROG8: R812.2, R813.1, U28.3 (PROG)
/BR_PULL1: Q31.3 (C), R116.1
/BR_PULL2: Q32.3 (C), R216.1
/BR_PULL3: Q33.3 (C), R316.1
/BR_PULL4: Q34.3 (C), R416.1
/BR_PULL5: Q35.3 (C), R516.1
/BR_PULL6: Q36.3 (C), R616.1
/BR_PULL7: Q37.3 (C), R716.1
/BR_PULL8: Q38.3 (C), R816.1
/BR_REF1: R112.1, U21.2 (VREF)
/BR_REF2: R212.1, U22.2 (VREF)
/BR_REF3: R312.1, U23.2 (VREF)
/BR_REF4: R412.1, U24.2 (VREF)
/BR_REF5: R512.1, U25.2 (VREF)
/BR_REF6: R612.1, U26.2 (VREF)
/BR_REF7: R712.1, U27.2 (VREF)
/BR_REF8: R812.1, U28.2 (VREF)
/BR_SENSE1: Q11.5 (D_MB), R120.2, U21.13 (SENSE)
/BR_SENSE2: Q12.5 (D_MB), R220.2, U22.13 (SENSE)
/BR_SENSE3: Q13.5 (D_MB), R320.2, U23.13 (SENSE)
/BR_SENSE4: Q14.5 (D_MB), R420.2, U24.13 (SENSE)
/BR_SENSE5: Q15.5 (D_MB), R520.2, U25.13 (SENSE)
/BR_SENSE6: Q16.5 (D_MB), R620.2, U26.13 (SENSE)
/BR_SENSE7: Q17.5 (D_MB), R720.2, U27.13 (SENSE)
/BR_SENSE8: Q18.5 (D_MB), R820.2, U28.13 (SENSE)
/BR_TIMER1: C111.1, C112.1, TP17.1, U21.4 (TIMER)
/BR_TIMER2: C211.1, C212.1, TP18.1, U22.4 (TIMER)
/BR_TIMER3: C311.1, C312.1, TP19.1, U23.4 (TIMER)
/BR_TIMER4: C411.1, C412.1, TP20.1, U24.4 (TIMER)
/BR_TIMER5: C511.1, C512.1, TP21.1, U25.4 (TIMER)
/BR_TIMER6: C611.1, C612.1, TP22.1, U26.4 (TIMER)
/BR_TIMER7: C711.1, C712.1, TP23.1, U27.4 (TIMER)
/BR_TIMER8: C811.1, C812.1, TP24.1, U28.4 (TIMER)
/BUS_DIV: R26.2, R27.1, R28.1
/CAP_MAIN: C17.1, U12.11 (CAP)
/CAP_USB: C22.1, U13.11 (CAP)
/CC1: J4.A5 (CC1), R7.1
/CC2: J4.B5 (CC2), R8.1
/CHFEED1: D111.2 (K_TAB), F1.2 (COM), Q11.2 (S), Q11.3 (S), Q11.4 (S), R116.2, R117.1
/CHFEED2: D211.2 (K_TAB), F2.2 (COM), Q12.2 (S), Q12.3 (S), Q12.4 (S), R216.2, R217.1
/CHFEED3: D311.2 (K_TAB), F3.2 (COM), Q13.2 (S), Q13.3 (S), Q13.4 (S), R316.2, R317.1
/CHFEED4: D411.2 (K_TAB), F4.2 (COM), Q14.2 (S), Q14.3 (S), Q14.4 (S), R416.2, R417.1
/CHFEED5: D511.2 (K_TAB), F5.2 (COM), Q15.2 (S), Q15.3 (S), Q15.4 (S), R516.2, R517.1
/CHFEED6: D611.2 (K_TAB), F6.2 (COM), Q16.2 (S), Q16.3 (S), Q16.4 (S), R616.2, R617.1
/CHFEED7: D711.2 (K_TAB), F7.2 (COM), Q17.2 (S), Q17.3 (S), Q17.4 (S), R716.2, R717.1
/CHFEED8: D811.2 (K_TAB), F8.2 (COM), Q18.2 (S), Q18.3 (S), Q18.4 (S), R816.2, R817.1
/DEN: R102.1, R202.1, R302.1, R402.1, R502.1, R602.1, R702.1, R802.1, U10.31 (IO38)
/DENR1: R102.2, U1.3 (DEN)
/DENR2: R202.2, U2.3 (DEN)
/DENR3: R302.2, U3.3 (DEN)
/DENR4: R402.2, U4.3 (DEN)
/DENR5: R502.2, U5.3 (DEN)
/DENR6: R602.2, U6.3 (DEN)
/DENR7: R702.2, U7.3 (DEN)
/DENR8: R802.2, U8.3 (DEN)
/DGATE_MAIN: Q1.4 (G), Q2.4 (G), U12.1 (DGATE)
/DGATE_USB: Q5.4 (G), U13.1 (DGATE)
/EN: C11.1, R5.2, SW1.2, U10.3 (EN)
/GATE_Q3: Q3.1 (G), R16.2
/GATE_Q4: Q4.1 (G), R19.2
/HGATE_MAIN: R16.1, R19.1, TP7.1, U14.12 (GATE)
/HS_PROG: R17.2, R18.1, U14.3 (PROG)
/HS_REF: Q6.2 (E), R17.1, R22.2, U14.2 (VREF)
/HS_SENSE: R20.4 (S_OUT), TP5.1, U14.13 (SENSE)
/HS_TIMER: C18.1, C25.1, C28.1, TP6.1, U14.4 (TIMER)
/HS_VCC: R20.3 (S_IN), TP4.1, U14.14 (VCC)
/IN1: R101.1, U10.8 (IO15)
/IN2: R201.1, U10.19 (IO11)
/IN3: R301.1, U10.20 (IO12)
/IN4: R401.1, U10.21 (IO13)
/IN5: R501.1, U10.22 (IO14)
/IN6: R601.1, U10.23 (IO21)
/IN7: R701.1, U10.24 (IO47)
/IN8: R801.1, U10.25 (IO48)
/INR1: R101.2, R108.1, U1.2 (IN)
/INR2: R201.2, R208.1, U2.2 (IN)
/INR3: R301.2, R308.1, U3.2 (IN)
/INR4: R401.2, R408.1, U4.2 (IN)
/INR5: R501.2, R508.1, U5.2 (IN)
/INR6: R601.2, R608.1, U6.2 (IN)
/INR7: R701.2, R708.1, U7.2 (IN)
/INR8: R801.2, R808.1, U8.2 (IN)
/IO0: R6.2, SW2.2, U10.27 (IO0)
/IS1: C103.1, D101.3 (COM), R105.2, U10.39 (IO1)
/IS2: C203.1, D201.3 (COM), R205.2, U10.15 (IO3)
/IS3: C303.1, D301.3 (COM), R305.2, U10.4 (IO4)
/IS4: C403.1, D401.3 (COM), R405.2, U10.38 (IO2)
/IS5: C503.1, D501.3 (COM), R505.2, U10.6 (IO6)
/IS6: C603.1, D601.3 (COM), R605.2, U10.18 (IO10)
/IS7: C703.1, D701.3 (COM), R705.2, U10.12 (IO8)
/IS8: C803.1, D801.3 (COM), R805.2, U10.17 (IO9)
/ISP1: R104.1, R105.1, U1.4 (IS)
/ISP2: R204.1, R205.1, U2.4 (IS)
/ISP3: R304.1, R305.1, U3.4 (IS)
/ISP4: R404.1, R405.1, U4.4 (IS)
/ISP5: R504.1, R505.1, U5.4 (IS)
/ISP6: R604.1, R605.1, U6.4 (IS)
/ISP7: R704.1, R705.1, U7.4 (IS)
/ISP8: R804.1, R805.1, U8.4 (IS)
/LEDK1: D102.2 (A), D103.2 (K), R107.2
/LEDK2: D202.2 (A), D203.2 (K), R207.2
/LEDK3: D302.2 (A), D303.2 (K), R307.2
/LEDK4: D402.2 (A), D403.2 (K), R407.2
/LEDK5: D502.2 (A), D503.2 (K), R507.2
/LEDK6: D602.2 (A), D603.2 (K), R607.2
/LEDK7: D702.2 (A), D703.2 (K), R707.2
/LEDK8: D802.2 (A), D803.2 (K), R807.2
/LOAD1: C102.1, F1.3 (LOAD), J1.2, R106.1, R107.1, U1.8 (OUT), U1.9 (OUT), U1.10 (OUT), U1.12 (OUT), U1.13 (OUT), U1.14 (OUT)
/LOAD2: C202.1, F2.3 (LOAD), J6.2, R206.1, R207.1, U2.8 (OUT), U2.9 (OUT), U2.10 (OUT), U2.12 (OUT), U2.13 (OUT), U2.14 (OUT)
/LOAD3: C302.1, F3.3 (LOAD), J7.2, R306.1, R307.1, U3.8 (OUT), U3.9 (OUT), U3.10 (OUT), U3.12 (OUT), U3.13 (OUT), U3.14 (OUT)
/LOAD4: C402.1, F4.3 (LOAD), J8.2, R406.1, R407.1, U4.8 (OUT), U4.9 (OUT), U4.10 (OUT), U4.12 (OUT), U4.13 (OUT), U4.14 (OUT)
/LOAD5: C502.1, F5.3 (LOAD), J9.2, R506.1, R507.1, U5.8 (OUT), U5.9 (OUT), U5.10 (OUT), U5.12 (OUT), U5.13 (OUT), U5.14 (OUT)
/LOAD6: C602.1, F6.3 (LOAD), J10.2, R606.1, R607.1, U6.8 (OUT), U6.9 (OUT), U6.10 (OUT), U6.12 (OUT), U6.13 (OUT), U6.14 (OUT)
/LOAD7: C702.1, F7.3 (LOAD), J11.2, R706.1, R707.1, U7.8 (OUT), U7.9 (OUT), U7.10 (OUT), U7.12 (OUT), U7.13 (OUT), U7.14 (OUT)
/LOAD8: C802.1, F8.3 (LOAD), J12.2, R806.1, R807.1, U8.8 (OUT), U8.9 (OUT), U8.10 (OUT), U8.12 (OUT), U8.13 (OUT), U8.14 (OUT)
/MAIN_FLT_N: R24.2, TP12.1, U10.35 (IO42), U14.9 (FLT_N)
/MAIN_IMON: R25.1, TP11.1, U14.6 (IMON)
/MAIN_PG_N: R21.1, TP13.1, U14.8 (PG_N)
/OV_MAIN: R12.2, R13.1, U14.5 (OV)
/RT: R1.1, U9.1 (RT)
/RXD0: J5.4, U10.36 (RXD0)
/STAT: R9.1, U10.34 (IO41)
/STATK: D5.2 (A), R9.2
/TXD0: J5.3, U10.37 (TXD0)
/UGND1: C104.2, R103.1, R108.2, U1.1 (GND)
/UGND2: C204.2, R203.1, R208.2, U2.1 (GND)
/UGND3: C304.2, R303.1, R308.2, U3.1 (GND)
/UGND4: C404.2, R403.1, R408.2, U4.1 (GND)
/UGND5: C504.2, R503.1, R508.2, U5.1 (GND)
/UGND6: C604.2, R603.1, R608.2, U6.1 (GND)
/UGND7: C704.2, R703.1, R708.2, U7.1 (GND)
/UGND8: C804.2, R803.1, R808.2, U8.1 (GND)
/USB_D+: J4.A6 (D+), J4.B6 (D+), R10.1, U11.1 (IO1), U11.6 (IO4)
/USB_D-: J4.A7 (D-), J4.B7 (D-), R11.1, U11.3 (IO2), U11.4 (IO3)
/USB_MCU_D+: R10.2, U10.14 (USB_D+)
/USB_MCU_D-: R11.2, U10.13 (USB_D-)
/UV_MAIN: R14.2, R15.1, U14.1 (UVEN)
/V12F: D1.2 (A), F9.2
/VCC_BUCK: C14.1, U9.23 (VCC)
/VIN: C1.1, C2.1, C3.1, C21.1, C22.2, D1.1 (K), Q5.5 (D), TP9.1, U9.2 (EN/SYNC), U9.3 (VIN), U9.4 (VIN), U9.18 (VIN), U9.19 (VIN), U13.3 (VSNS), U13.4 (SW), U13.9 (OUT), U13.10 (VS), U13.12 (C)
/VS1: C101.1, C104.1, F1.1 (SW), U1.15 (VS)
/VS2: C201.1, C204.1, F2.1 (SW), U2.15 (VS)
/VS3: C301.1, C304.1, F3.1 (SW), U3.15 (VS)
/VS4: C401.1, C404.1, F4.1 (SW), U4.15 (VS)
/VS5: C501.1, C504.1, F5.1 (SW), U5.15 (VS)
/VS6: C601.1, C604.1, F6.1 (SW), U6.15 (VS)
/VS7: C701.1, C704.1, F7.1 (SW), U7.15 (VS)
/VS8: C801.1, C804.1, F8.1 (SW), U8.15 (VS)
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

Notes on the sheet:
CHANNEL 1
CHANNEL 2
CHANNEL 3
CHANNEL 4
CHANNEL 5
CHANNEL 6
CHANNEL 7
CHANNEL 8
MCU: IS1-8 -> ADC1 IO1,3,4,2,6,10,8,9; IN1 -> IO15; IMON -> IO5; BUS -> IO7; see pin map
LOGIC: protected +12V -> F9 -> D1 -> VIN; USB -> Q5 ideal diode -> VIN; TPSM63603V3 -> 3V3
INPUT: 9.5-16V; U12 reverse block; U14 current/power limit + latch-off; U12/U13 RTN FLOAT
I/O: J1, J6-J12 direct-entry load terminals: pin 1=GND, pin 2=LOAD+
SUPPLY: 9.5-16V house bank via upstream fuse; USB initial programming only, battery disconnected
8-channel PROFET+2 12 V load switch with 3-position ATO fuse bypass

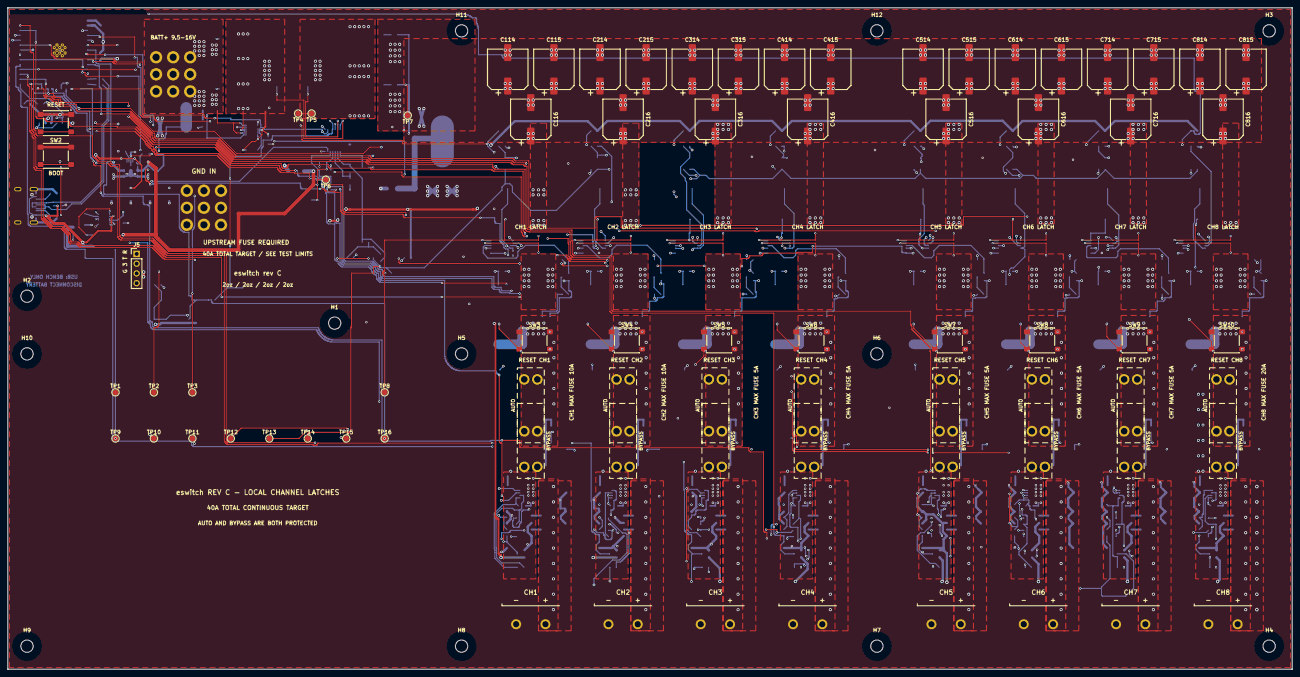
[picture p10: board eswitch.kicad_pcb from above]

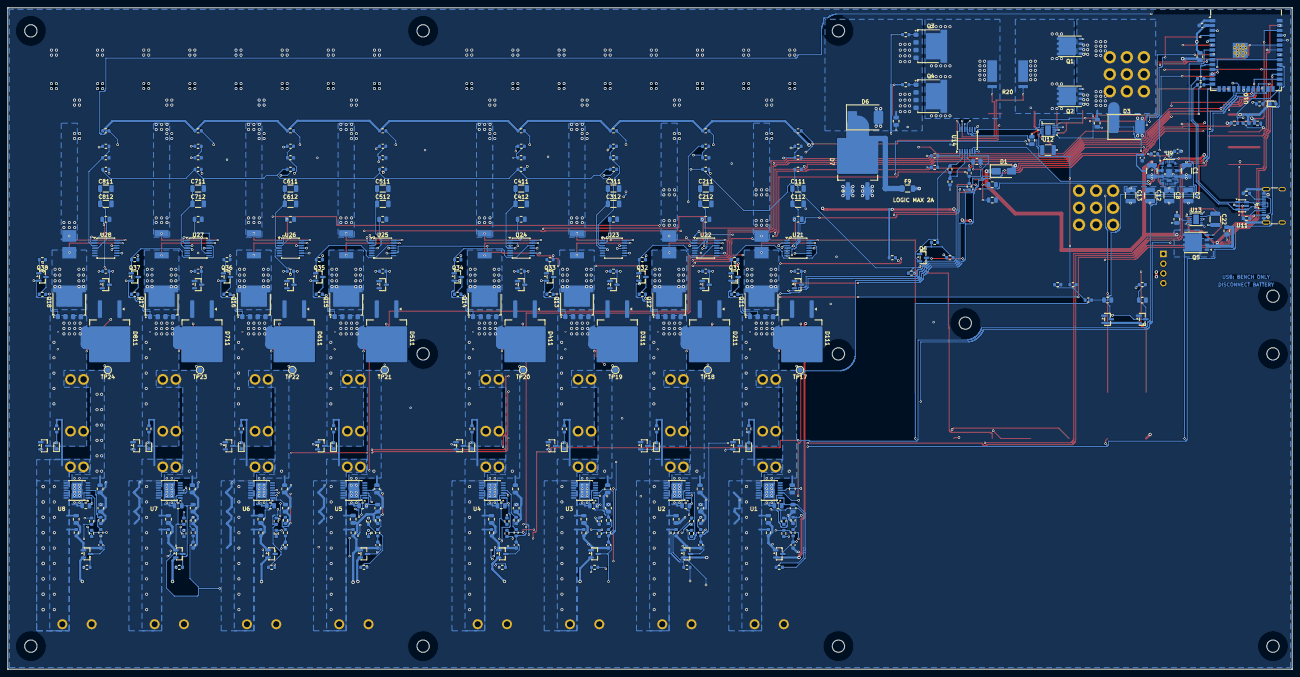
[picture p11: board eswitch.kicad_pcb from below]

Board: 4 copper layers, 334.0 x 172.0 mm, 415 parts (334 on the bottom side), 207 nets.

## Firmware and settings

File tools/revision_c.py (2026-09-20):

"""Revision C circuit: independent latching breakers before both fuse positions.

Values are checked independently by channel_isolation_analysis.py. No firmware
or 3V3 supply is needed to enable, trip, or reset a branch breaker.
"""
from design import R0603, C0805, SOT23, CHANNELS

W, H = 334.0, 172.0
CX = [136., 160., 184., 208., 244., 268., 292., 316.]
MOUNTS = [(85, 82), (5, 75), (328, 6), (328, 166),
          (118, 90), (226, 90), (226, 166), (118, 166),
          (5, 166), (5, 90), (118, 6), (226, 6)]
FAULT_PINS = ['9', '10', '11', '28', '29', '30', '32', '33']
SHUNT_COUNT = {n: 1 for n in range(1, 9)}
SHUNT_MOHM = {n: (2 if n == 8 else 4 if n <= 2 else 8) for n in range(1, 9)}


def apply(parts_list, add):
    p = {x.ref: x for x in parts_list}
    p['J4'].footprint = 'eswitch:USB4105_NPTH_0p2'
    p['R20'].value = '0.5mR 1% 5W'
    p['R20'].fields.update(MPN='CSS4J-4026R-L500F',
        Note='Four-terminal common backup limit; coordinated above one branch fault plus 40A healthy load')
    p['C18'].value = '12nF 50V C0G 5%'
    p['C18'].fields.update(MPN='C0805C123J5GACTU',Manufacturer='KEMET')
    p['R17'].value = '8.25k 0.1%'
    p['R17'].fields.update(MPN='RT0603BRD078K25L', Manufacturer='YAGEO')
    p['R18'].value = '1k 0.1%'
    p['R18'].fields.update(MPN='RT0603BRD071KL', Manufacturer='YAGEO')
    p['U14'].pins.update({'6':'MAIN_IMON', '8':'MAIN_PG_N', '9':'MAIN_FLT_N'})
    p['U14'].fields['Note'] = 'Common bus backup current/power limit; branch breakers provide output-fault isolation'
    p['U10'].pins.pop('7')
    p['U10'].pins.update({'8':'IN1', '5':'ADC_IMON', '7':'ADC_BUS', '35':'MAIN_FLT_N'})
    for n, pin in enumerate(FAULT_PINS, 1):
        p['U10'].pins[pin] = f'BR_FLT{n}'
    for i, xy in enumerate(MOUNTS[4:], 5):
        add(f'H{i}', 'Mechanical:MountingHole', 'M3',
            'MountingHole:MountingHole_3.2mm_M3', {}, (650+(i-5)*12.7, 400))

    # PG is active LOW. Invert from the always-available 4V reference, so the
    # main bus charges before branch startup and BYPASS survives an MCU fault.
    add('Q6', 'Transistor_BJT:MMBT3906', 'MMBT3906LT1G', SOT23,
        {1:'BR_ENABLE_BASE', 2:'HS_REF', 3:'BR_ENABLE'}, (650, 240),
        MPN='MMBT3906LT1G', Manufacturer='onsemi',
        Datasheet='https://www.onsemi.com/pdf/datasheet/mmbt3906lt1-d.pdf')
    def resistor(ref, value, pins, xy, **kw):
        return add(ref, 'Device:R', value, R0603, pins, xy, **kw)
    resistor('R21','10k',{1:'MAIN_PG_N',2:'BR_ENABLE_BASE'},(620,270))
    resistor('R22','47k',{1:'BR_ENABLE_BASE',2:'HS_REF'},(640,270))
    resistor('R23','47k',{1:'BR_ENABLE',2:'GND'},(660,270))
    resistor('R24','10k',{1:'+3V3',2:'MAIN_FLT_N'},(680,270))
    resistor('R25','47k',{1:'MAIN_IMON',2:'ADC_IMON'},(620,310))
    resistor('R26','115k 0.1%',{1:'+12V',2:'BUS_DIV'},(640,310))
    resistor('R27','10k 0.1%',{1:'BUS_DIV',2:'GND'},(660,310))
    resistor('R28','47k',{1:'BUS_DIV',2:'ADC_BUS'},(680,310))
    for ref, net, x in [('C23','ADC_IMON',620),('C24','ADC_BUS',650)]:
        add(ref,'Device:C','10nF 50V',C0805,{1:net,2:'GND'},(x,345))
    for ref, net, x in [('D8','ADC_IMON',680),('D9','ADC_BUS',710)]:
        add(ref,'Diode:BAT54S','BAT54S',SOT23,{1:'GND',2:'+3V3',3:net},(x,345))
    add('C25','Device:C','12nF 50V C0G 5%',C0805,
        {1:'HS_TIMER',2:'GND'},(720,270),MPN='C0805C123J5GACTU',Manufacturer='KEMET',
        Note='C18/C25/C28 in parallel: common timer 36nF')
    add('C28','Device:C','12nF 50V C0G 5%',C0805,
        {1:'HS_TIMER',2:'GND'},(740,270),MPN='C0805C123J5GACTU',Manufacturer='KEMET',
        Note='C18/C25/C28 in parallel: common timer 36nF')
    for n in range(1,9):
        x, y = 35 + ((n-1)%4)*250, 465 + ((n-1)//4)*170.18
        feed, sense = f'CHFEED{n}', f'BR_SENSE{n}'
        p[f'F{n}'].pins['2'] = feed
        p[f'F{n}'].fields['Note'] = f'CH{n}: both AUTO and BYPASS are downstream of independent hardware latch'
        add(f'U{20+n}', 'eswitch:TPS2492', 'TPS2492 (CHANNEL LATCH)',
            'Package_SO:TSSOP-14_4.4x5mm_P0.65mm',
            {1:f'BR_EN{n}',2:f'BR_REF{n}',3:f'BR_PROG{n}',4:f'BR_TIMER{n}',
             5:'GND',7:'GND',9:f'BR_FLT{n}',11:f'BR_OUT{n}',12:f'BR_GATE{n}',
             13:sense,14:'+12V'}, (x+55,y),
            MPN='TPS2492PWR',Manufacturer='Texas Instruments',
            Datasheet='https://www.ti.com/lit/ds/symlink/tps2492.pdf',
            Note=f'CH{n} local latch; reset only with SW{n+2}; OV handled by U14')
        add(f'Q{10+n}','eswitch:PSMN1R8-80SSE','PSMN1R8-80SSE',
            'Package_TO_SOT_SMD:LFPAK88',
            {1:f'BR_GS{n}',2:feed,3:feed,4:feed,5:sense},(x+115,y),
            MPN='PSMN1R8-80SSEJ',Manufacturer='Nexperia',
            Datasheet='https://assets.nexperia.com/documents/data-sheet/PSMN1R8-80SSE.pdf',
            Note=f'CH{n}: enhanced SOA, one device carries all branch linear stress')
        for k in range(3):
            add(f'C{n}{14+k}','Device:C_Polarized','120uF 35V polymer',
                'Capacitor_SMD:CP_Elec_10x12.6', {1:'+12V',2:'GND'},(x+100+k*22.86,y+130),
                MPN='35SVPF120M',Manufacturer='Panasonic Industry',
                Datasheet='https://industrial.panasonic.com/ww/products/pt/os-con/models/35SVPF120M',
                Note='Common reservoir: 24 parallel 120uF/18mOhm capacitors distributed along bus')
        milliohms=SHUNT_MOHM[n]
        add(f'R{n}20','Device:R',f'{milliohms}mR 1% 3W',
            'eswitch:WSLP2512_8m' if milliohms==8 else 'eswitch:WSLP2512_2m',
            {1:'+12V',2:sense},(x,y+45.72),
            MPN=f'WSLP2512{milliohms}L000FEA',Manufacturer='Vishay Dale',
            Datasheet='https://www.vishay.com/docs/30122/wslp.pdf',
            Note='Independent Kelvin pickup at both shunt lands; no series PCB interconnect in the sensed resistance')
        for ref, value, pins, xx in [
            (f'R{n}11','100R',{1:f'BR_GATE{n}',2:f'BR_GS{n}'},x),
            (f'R{n}12','7.5k' if n==8 else '2.2k' if n in range(3,8) else '4.7k',
                {1:f'BR_REF{n}',2:f'BR_PROG{n}'},x+20.32),
            (f'R{n}13','1k',{1:f'BR_PROG{n}',2:'GND'},x+40.64),
            (f'R{n}14','47k',{1:'BR_ENABLE',2:f'BR_EN{n}'},x+60.96),
            (f'R{n}15','10k',{1:'+3V3',2:f'BR_FLT{n}'},x+81.28),
        ]:
            fields={}
            if ref==f'R{n}11': fields=dict(MPN='RC0603FR-07100RL',Manufacturer='YAGEO')
            if ref==f'R{n}12':
                mpn,maker={'7.5k':('RT0603BRD077K5L','YAGEO'),
                    '4.7k':('RT0603BRD074K7L','YAGEO'),
                    '2.2k':('RG1608P-222-B-T5','Susumu')}[value]
                fields=dict(MPN=mpn,Manufacturer=maker); value+=' 0.1%'
            if ref==f'R{n}13':
                fields=dict(MPN='RT0603BRD071KL',Manufacturer='YAGEO'); value+=' 0.1%'
            resistor(ref,value,pins,(xx,y+73.66),**fields)
        add(f'Q{30+n}', 'Transistor_BJT:MMBT3906', 'FMMT720TA', SOT23,
            {1:f'BR_GATE{n}',2:f'BR_GS{n}',3:f'BR_PULL{n}'},(x+175,y),
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

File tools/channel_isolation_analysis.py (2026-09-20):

#!/usr/bin/env python3
"""Revision C coordination and SOA screen from exact fitted circuit values.

Analytical tolerance screen, not measured short-circuit or thermal qualification.
"""
import itertools
import json
import math
import sys
from pathlib import Path
import design
from revision_c import SHUNT_MOHM
from input_stage_analysis import charge_time, constant_load_charge_time, divider
from input_stage_transient import soa_current

ROOT=Path(__file__).resolve().parent.parent


def power(top,rs,tol):
    v=[ref*rb/(rt+rb)+ib*rt*rb/(rt+rb)
       for ref,rb,rt,ib in itertools.product((3.9,4.1),(990,1010),
                                            (top*.99,top*1.01),(-5e-6,5e-6))]
    return [.5*min(v)/(rs*(1+tol))*.68,.5*max(v)/(rs*(1-tol))*1.32]


def timer(cap,tol):
    return [cap*(1-tol)*3.9/36e-6,cap*(1+tol)*4.1/17e-6]


def analyze():
    p={x.ref:x for x in design.build()}
    assert p['R20'].fields['MPN']=='CSS4J-4026R-L500F'
    assert p['R17'].value=='8.25k 0.1%'
    assert p['R17'].fields['MPN']=='RT0603BRD078K25L'
    assert p['R18'].fields['MPN']=='RT0603BRD071KL'
    assert p['C18'].value==p['C25'].value==p['C28'].value=='12nF 50V C0G 5%'
    assert p['U14'].pins['8']=='MAIN_PG_N'
    assert p['Q6'].pins=={'1':'BR_ENABLE_BASE','2':'HS_REF','3':'BR_ENABLE'}
    # Shunt tolerance includes full -55..155C terminal temperature range.
    # 0.5m Bourns: 1% + 100ppm/K * 130K -> reserve 2.5%.
    # Worst WSLP2m: 1% + 275ppm/K * 130K; reserve 6% with local Kelvin lands.
    common_r=.0005
    common_i=[.045/(common_r*1.025),.055/(common_r*.975)]
    common_p=power(8250,common_r,.025)
    # PROG remains within the specified 0.4..4V range including bias/tolerance.
    assert 3.9*990/(8250*1.01+990)-5e-6*1000 > .4
    common_t=timer(36e-9,.055)
    soa=json.loads((ROOT/'docs/evidence/input-mosfet-soa.json').read_text())
    derate=(175-60)/150*.9
    common_soa=common_p[1]/16/(soa_current(soa['curves']['10ms'],16)*derate)
    assert common_t[1]<.01 and common_soa<1, 'Common backup fault exceeds single-FET 10ms SOA'
    common_start=[]
    for v in (9.5,12,16):
        dt=constant_load_charge_time(v,3480e-6,2,common_p[0],common_i[0])
        budget=36e-9*.945*(3.9-1.04)/36e-6
        assert dt*1.25<budget,(v,dt,budget)
        common_start.append(dict(input_v=v,capacitance_uf=3480,load_current_a=2,
                                 ideal_charge_ms=dt*1000,minimum_timer_residual_ms=budget*1000))
    branches=[]
    for n in range(1,9):
        rating=design.CHANNELS[n][0]; rs=.001*SHUNT_MOHM[n]
        assert p[f'R{n}20'].fields['MPN']==f'WSLP2512{SHUNT_MOHM[n]}L000FEA'
        assert p[f'F{n}'].pins['2']==f'CHFEED{n}'
        assert p[f'Q{10+n}'].pins['5']==f'BR_SENSE{n}'
        assert p[f'U{20+n}'].pins['1']==f'BR_EN{n}'
        assert p[f'SW{n+2}'].pins=={'1':'GND','2':f'BR_EN{n}'}
        assert p[f'R{n}12'].value==('7.5k' if n==8 else '2.2k' if rating==5 else '4.7k')+' 0.1%'
        assert p[f'R{n}13'].fields['MPN']=='RT0603BRD071KL'
        for k in (1,2): assert p[f'C{n}{10+k}'].fields['MPN']=='C1206C104J5JACAUTO'
        currents=[.045/(rs*1.06),.055/(rs*.94)]
        powers=power(7500 if n==8 else 2200 if rating==5 else 4700,rs,.06)
        # U2J -750 +/-120ppm/K; <9% over specified temperature excursion,
        # plus initial 5%. Use +/-15% total, no Class-II DC-bias dependence.
        times=timer(200e-9,.15)
        residual=200e-9*.85*(3.9-1.04)/36e-6
        cases=[]
        for v in (9.5,12,16):
            startup_rating=10 if n==8 else rating
            dt=charge_time(v,.001,startup_rating,powers[0],currents[0])
            assert dt*1.25<residual,(n,v,dt,residual)
            # Compare all branch current to ONE FET, at 60C mounting base,
            # with 10% margin to the digitized 100ms datasheet SOA curve.
            util=(powers[1]/v)/(soa_current(soa['curves']['100ms'],v)*derate)
            assert util<1,(n,v,util)
            cases.append(dict(input_v=v,startup_load_a=startup_rating,load_model='resistor at stated startup current plus 1000uF actual',
                              ideal_charge_ms=dt*1000,minimum_residual_timer_ms=residual*1000,
                              single_fet_100ms_power_limit_soa_utilization=util))
        healthy_fault=40+currents[1]
        assert healthy_fault<common_i[0]
        branches.append(dict(channel=n,fuse_a=rating,shunt_ohm=rs,
            current_limit_a=currents,power_limit_screen_w=powers,
            timer_from_zero_ms=[x*1000 for x in times],
            healthy_40a_plus_one_fault_a=healthy_fault,
            common_trip_headroom_a=common_i[0]-healthy_fault,
            shunt_dissipation_at_rating_w=rating**2*rs,
            startup_cases=cases))
    return dict(status='prototype_engineering_screen_not_measured_rating',revision='C',
        current_limit_a=common_i,power_limit_screen_w=common_p,
        nominal_power_limit_w=.5*(4/9.25)/common_r,
        common_backup_single_fet_10ms_soa_utilization=common_soa,
        timer_from_zero_ms=[x*1000 for x in common_t],
        ov_rising_v=divider(115000,10000,.001,(1.31,1.39),(-1e-6,1e-6)),
        uv_rising_v=divider(56200,10000,.001,(1.31,1.39),(-1e-6,1e-6)),
        common_startup=common_start,branches=branches,
        imon_volts_per_amp=48*common_r,bus_divider_ratio=10000/125000,
        assumptions=[
          '9.5..16V at board input under the specified load; 40A total continuous target remains a bench qualification item',
          'One output fault; healthy aggregate current <=40A; no common supply or ground fault',
          'Common 3480uF maximum actual capacitance includes 24x120uF +20% and board/logic capacitance',
          'PG blocks branch startup during common capacitor charging; its 5..15ms deglitch filters short disturbances',
          '1000uF maximum actual branch load capacitance, resistor startup load: 10A CH1/2/8, 5A CH3..7',
          'PROG divider resistors: 0.1%, 25ppm/K; 1% total resistance budget covers initial tolerance, temperature and aging reserve',
          'Each single shunt uses a conservative 6% resistance budget including terminal TCR and Kelvin land pickup; verify effective resistance on first board',
          'TI power-engine +/-32% is a test-point extrapolation, not a guaranteed PROG-range bound',
          'Ideal charge calculations omit gate dynamics; separate SPICE sensitivity study is required',
          'Common backup trip is about 88..113A; it is not a 40A continuous thermal limiter',
          'Current coordination prevents a sustained single-branch fault from reaching the input trip; overshoot and bus dips require transient validation',
          'Local latch resets only through its UVEN switch or loss of the shared enable/input; no MCU action is required'],
        sources={'controller':'https://www.ti.com/lit/gpn/tps2492',
                 'shunt':'https://www.vishay.com/docs/30122/wslp.pdf',
                 'mosfet':'https://assets.nexperia.com/documents/data-sheet/PSMN1R8-80SSE.pdf'})
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

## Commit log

2026-09-13 eswitch: 8ch PROFET+2 12V load switch with fuse bypass, generated KiCad 10 design
    Script-generated schematic, custom libs, 4-layer PCB generator and freerouting flow.
    Schematic passes ERC and a netlist check against tools/design.py; PCB routing in progress.
    [eswitch.kicad_pcb, eswitch.kicad_sch]
2026-09-13 Routing flow: keep-outs over power strips, net classes re-applied, terminal pin order fix
2026-09-13 3D models for project footprints (fuse holder, screw terminal, terminal block)
2026-09-13 README: routing flow and 3D notes; mise: full KiCad AppImage; USB-C orientation, island removal, stitching
2026-09-13 Routed board: DRC clean (0 copper violations, 0 unconnected), 3D models, KiCad 10 native format
    - freerouting with temporary keep-outs, post-route prune/fix/stitch (tools/finish.py, tools/stitch.py)
    - USB-C D+/D- pair tie-offs and VBUS on In2, CC2 hand-routed
    - design rules and net classes persisted in eswitch.kicad_pro
    - schematic and board upgraded to KiCad 10 file format
    [eswitch.kicad_pcb, eswitch.kicad_sch]
2026-09-13 Fabrication packages for JLCPCB and PCBWay (tools/fab_package.py, fab/)
    [eswitch-bom.csv, eswitch.kicad_pcb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]
2026-09-13 BOM: manufacturer + MPN for every part, DigiKey upload CSV, off-board extras
    [eswitch-bom.csv, eswitch-digikey-bom.csv, eswitch.kicad_sch]
2026-09-13 Channel ratings 2x10A/5x5A/1x20A with BTS7004/7008/7002, 1 oz copper strategy, USB-C tie-off rework
    [eswitch.kicad_sch]
2026-09-14 Routed 1 oz board: 2x10A/5x5A/1x20A channels, DRC clean (0 copper violations, 0 unconnected)
    - BTS7004/7008/7002 per rating, per-channel RSENSE, CH8 (20 A) with parallel In2 copper
    - IS4 moved to IO2; decoupling/pull-ups re-placed; USB-C D+/D- tie-offs on opposite sides
    - finish.py: post-route prune, fix-ups, clearance-checked grid router for hand routes
    - fab/: regenerated gerbers, BOMs (DigiKey/JLCPCB/PCBWay), CPLs, 1 oz stack-up note
    [eswitch-bom.csv, eswitch-digikey-bom.csv, eswitch.kicad_pcb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]
2026-09-14 Apply review corrections and circuit/fuse silk; hold fabrication
    Add dated three-board DigiKey BOM for manual assembly, direct-entry outputs and higher-current input terminals. Mark each fuse with circuit identity and maximum fuse size. Preserve legacy fabrication files in a do-not-order archive and gate new outputs on release checks.
    Not order-ready: eight signal connections remain after input terminal migration; native parity and electrical/layout/thermal findings are documented in docs/critical-review.md.
    [eswitch-bom.csv, eswitch-digikey-bom.csv, eswitch.kicad_pcb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]
2026-09-15 Finish reviewed PCB routing and release checks
    [eswitch-digikey-bom.csv, eswitch.kicad_pcb, eswitch.kicad_sch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]
2026-09-16 Checkpoint unfinished revision B power protection and PCB review
    [eswitch-digikey-bom.csv, eswitch.kicad_pcb, eswitch.kicad_sch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]
2026-09-19 Release revision B for prototype fabrication
    Complete the routed PCB, capacitor correction, startup and SOA screening, and owner-confirmed physical-fit review. Include the verified fabrication package, three-board BOM, release gates, and controlled bring-up plan. Keep production qualification and the measured 40 A rating pending hardware validation.
    [eswitch-B_Cu.gbl, eswitch-B_Mask.gbs, eswitch-B_Paste.gbp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]
2026-09-19 Publish DigiKey BOM quantities per board
    Keep ordering multiples with the purchaser. Generate one-module quantities, clarify assembly and package notes, and refresh the verified prototype package without changing the circuit or fitted parts.
    [eswitch-B_Cu.gbl, eswitch-B_Mask.gbs, eswitch-B_Paste.gbp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]
2026-09-20 Release revision C with independent channel protection
    Add hardware fault isolation for every AUTO and BYPASS output, complete the layout corrections, and update monitoring and bring-up documentation.
    Include verified prototype fabrication packages, CAM and JLC upload evidence, and per-unit BOM pricing. ERC, DRC, routing and schematic parity are clean; 29 transient cases pass.
    [cost-per-board.csv, cost-three-board-build.csv, economical-one-board-cart.csv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]
2026-10-25 Replace legacy designs with compact eight-channel switching bank
2026-10-26 Rework power copper and package expanded prototype for fabrication
2026-10-27 Release PROTO-PWR3 shared AUTO protection and passive bypass prototype
